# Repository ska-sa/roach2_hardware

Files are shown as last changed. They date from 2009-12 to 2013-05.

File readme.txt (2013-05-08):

Welcome to the GitHub repository for Roach 2 

change_log - contains details of the updates from rev 1 to Rev 2
design - contains calculations and estimates used in the design process
design_files - contains the Altium schematic and PCB files
release - contains the release files required for manufacturing and assembly

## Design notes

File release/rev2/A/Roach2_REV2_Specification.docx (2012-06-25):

PCB Specification

Date: | 1 June 2011
Company: | SKA SA
Billing Address: | 17 Baker St, Rosebank, Johannesburg, South Africa
| PO Box 522940, Saxonwold, 2132
Postal Address: | To be defined
Contact: | Omer Mahgoub | Email: | omer@ska.ac.za
| | Tel: | +27 21 506 7362
| Philip Gibbs | Email: | philip.gibbs@ska.ac.za
| | Tel: | +27 21 506 7363

Board name: ROACH 2

Revision: 2

Release: A

PCB Details

PCB Specifications: | IPC 6012 Class 2
Finished Board Size: | 12 x 9.6 inches [305x244 mm]
PCB Type: | Multi-layer
Layer Count: | 16
Dielectric: | All dielectric layers to be Isola 370HR high temperature laminate
Nominal board Thickness: | 93 mil (2.38 mm); tolerance +/-10%
Hole tolerance: | +3mil for vias; +/- 3mil for component holes and slots
Finish: | ENIG
Soldermask: | Green
Silkscreen: | White
Minimum clearance: | 4 mil
Handling rails: | .5 inch (12.7mm) rails, V-scored

PCB Stackup

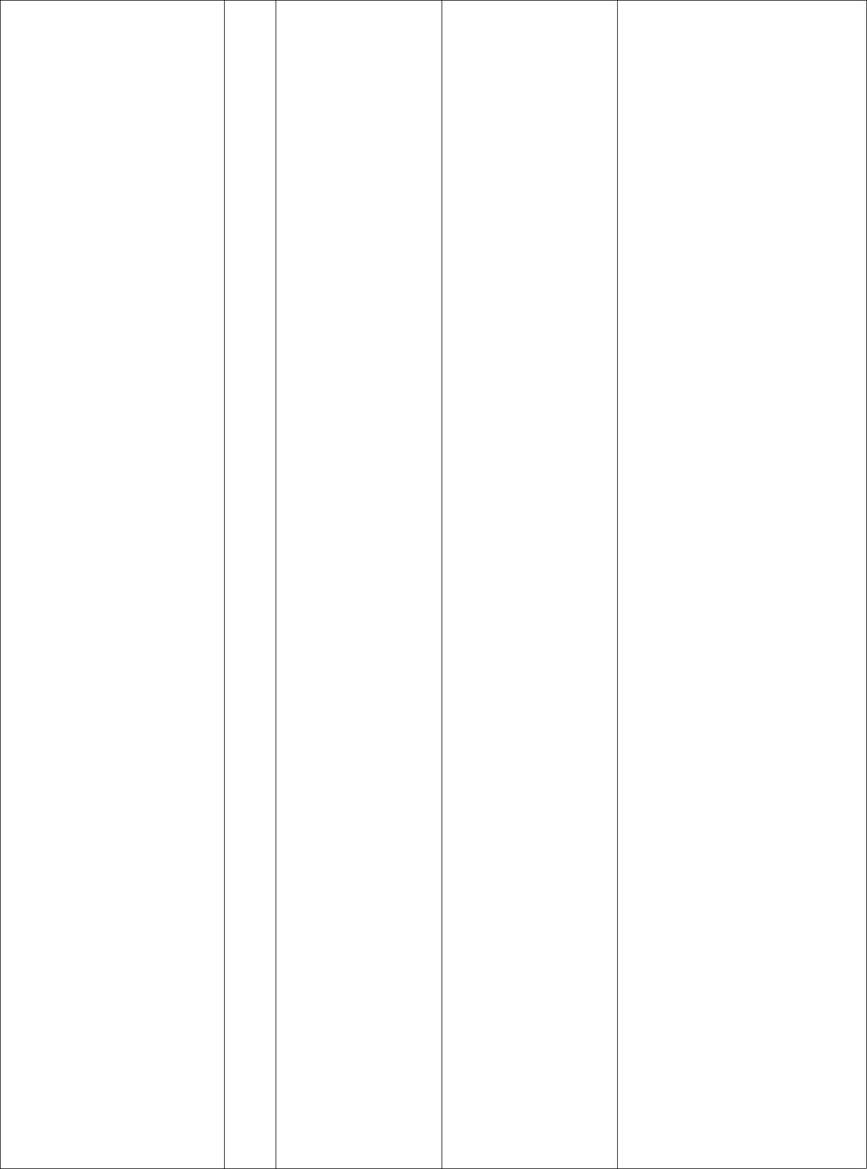
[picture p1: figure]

Layer | # | Copper (oz) | Dieletric (mil)** | Filename
Pastemask Top | | - | - | roach2.GTP
Silkscreen Top | | - | - | roach2.GTO
Soldermask Top | | - | - | roach2.GTS
Signal Top | 1 | 0.5 | | roach2.GTL
| | | 3mil
Ground 1 | 2 | 0.5 | | roach2.GP1
| | | 5mil
Signal 1 | 3 | 0.5 | | roach2.G1
| | | 5mil
Ground 2 | 4 | 0.5 | | roach2.GP2
| | | 5mil
Signal 2 | 5 | 0.5 | | roach2.G2
| | | 5mil
Power 1 | 6 | 1 | | roach2.GP3
| | | **
Ground 3 | 7 | 1 | | roach2.GP4
| | | 4mil
Signal 3 | 8 | 0.5 | | roach2.G3
| | | 4mil
Signal 4 | 9 | 0.5 | | roach2.G4
| | | 4mil
Power 2 | 10 | 1 | | roach2.GP5
| | | **
Power 3 | 11 | 1 | | roach2.GP6
| | | 5mil
Signal 5 | 12 | 0.5 | | roach2.G5
| | | 5mil
Power 4 | 13 | 0.5 | | roach2.GP7
| | | 5mil
Signal 6 | 14 | 0.5 | | roach2.G6
| | | 5mil
Ground 4 | 15 | 0.5 | | roach2.GP8
| | | 3mil
Signal Bottom | 16 | 0.5 | | roach2.GBL
Soldermask Bottom | | - | - | roach2.GBS
Silkscreen Bottom | | - | - | roach2.GBO
Pastemask Bottom | | - | - | roach2.GBP

* Thickness may be adjusted to achieve nominal total thickness of 93 mil, to satisfy impedance targets and to accommodate manufacturing processes.

Impedance Controlled Traces

All impedance matching to +/- 10%

Microstrip

Layers: Signal Top (#1), Signal Bottom (#16)

Target Impedance: 50 ohm

Trace thickness: 5 mil ( 127um )

Stripline

Layers: Layers: Signal 1 (#3), Signal 2 (#5), Signal 5 (#12), Signal 6 (#14)

Target Impedance: 50 ohm

Trace thickness: 3.8 mil ( 96.52 um )

Asymmetrical Stripline

Layers: Signal 3 (#8), Signal 4 (#9)

Target Impedance: 50 ohm

Trace thickness: 3.8 mil ( 96.52 um )

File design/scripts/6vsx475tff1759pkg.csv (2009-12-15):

N11 | 0 | INIT_B_0
N10 | 0 | DONE_0
AM11 | 0 | M1_0
AL10 | 0 | M2_0
P10 | 0 | HSWAPEN_0
M11 | 0 | PROGRAM_B_0
AL11 | 0 | M0_0
Y21 | 0 | AVSS_0
Y22 | 0 | AVDD_0
AA22 | 0 | VP_0
AB22 | 0 | VREFP_0
AB21 | 0 | VN_0
AA21 | 0 | VREFN_0
AC22 | 0 | DXP_0
AC21 | 0 | DXN_0
R10 | 0 | VBATT_0
L10 | 0 | DIN_0
J10 | 0 | RDWR_B_0
T10 | 0 | CSI_B_0
AK10 | 0 | DOUT_BUSY_0
K10 | 0 | CCLK_0
AR10 | 0 | TDO_0
AN10 | 0 | TCK_0
AN11 | 0 | TMS_0
AP10 | 0 | TDI_0
AH10 | 0 | VFS_0
AT37 | 12 | IO_L0P_12
AR38 | 12 | IO_L0N_12
AV39 | 12 | IO_L1P_12
AV38 | 12 | IO_L1N_12
AP37 | 12 | IO_L2P_12
AR37 | 12 | IO_L2N_12
AY39 | 12 | IO_L3P_12
BA39 | 12 | IO_L3N_12
AU37 | 12 | IO_L4P_12
AU38 | 12 | IO_L4N_VREF_12
AY38 | 12 | IO_L5P_12
AY37 | 12 | IO_L5N_12
AU36 | 12 | IO_L6P_12
AT36 | 12 | IO_L6N_12
BB39 | 12 | IO_L7P_12
BB38 | 12 | IO_L7N_12
AW37 | 12 | IO_L8P_SRCC_12
AW38 | 12 | IO_L8N_SRCC_12
AN35 | 12 | IO_L9P_MRCC_12
AN36 | 12 | IO_L9N_MRCC_12
AP36 | 12 | IO_L10P_MRCC_12
AP35 | 12 | IO_L10N_MRCC_12
BA37 | 12 | IO_L11P_SRCC_12
BB37 | 12 | IO_L11N_SRCC_12
AR35 | 12 | IO_L12P_VRN_12
AT35 | 12 | IO_L12N_VRP_12
BB36 | 12 | IO_L13P_12
BA36 | 12 | IO_L13N_12
AW36 | 12 | IO_L14P_12
AV36 | 12 | IO_L14N_VREF_12
BB34 | 12 | IO_L15P_12
BA34 | 12 | IO_L15N_12
AU34 | 12 | IO_L16P_12
AT34 | 12 | IO_L16N_12
BA35 | 12 | IO_L17P_12
AY35 | 12 | IO_L17N_12
AV34 | 12 | IO_L18P_12
AV35 | 12 | IO_L18N_12
AY34 | 12 | IO_L19P_12
AW35 | 12 | IO_L19N_12
AN40 | 13 | IO_L0P_13
AP40 | 13 | IO_L0N_13
AN41 | 13 | IO_L1P_13
AP41 | 13 | IO_L1N_13
AN39 | 13 | IO_L2P_13
AM39 | 13 | IO_L2N_13
AP42 | 13 | IO_L3P_13
AR42 | 13 | IO_L3N_13
AL37 | 13 | IO_L4P_13
AM38 | 13 | IO_L4N_VREF_13
AT42 | 13 | IO_L5P_13
AU42 | 13 | IO_L5N_13
AM34 | 13 | IO_L6P_13
AL35 | 13 | IO_L6N_13
AW42 | 13 | IO_L7P_13
AW41 | 13 | IO_L7N_13
AR40 | 13 | IO_L8P_SRCC_13
AT41 | 13 | IO_L8N_SRCC_13
AL34 | 13 | IO_L9P_MRCC_13
AK34 | 13 | IO_L9N_MRCC_13
AT40 | 13 | IO_L10P_MRCC_13
AU39 | 13 | IO_L10N_MRCC_13
AV41 | 13 | IO_L11P_SRCC_13
AU41 | 13 | IO_L11N_SRCC_13
AN38 | 13 | IO_L12P_VRN_13
AP38 | 13 | IO_L12N_VRP_13
AY42 | 13 | IO_L13P_13
BA42 | 13 | IO_L13N_13
AR39 | 13 | IO_L14P_13
AT39 | 13 | IO_L14N_VREF_13
BA41 | 13 | IO_L15P_13
BB41 | 13 | IO_L15N_13
AM37 | 13 | IO_L16P_13
AM36 | 13 | IO_L16N_13
BA40 | 13 | IO_L17P_13
AY40 | 13 | IO_L17N_13
AK35 | 13 | IO_L18P_13
AL36 | 13 | IO_L18N_13
AV40 | 13 | IO_L19P_13
AW40 | 13 | IO_L19N_13
AG34 | 14 | IO_L0P_14
AF34 | 14 | IO_L0N_14
AF40 | 14 | IO_L1P_14
AG41 | 14 | IO_L1N_14
AF39 | 14 | IO_L2P_14
AG39 | 14 | IO_L2N_14
AG42 | 14 | IO_L3P_14
AH41 | 14 | IO_L3N_14
AG38 | 14 | IO_L4P_14
AH38 | 14 | IO_L4N_VREF_14
AH40 | 14 | IO_L5P_14
AJ41 | 14 | IO_L5N_14
AF37 | 14 | IO_L6P_14
AG37 | 14 | IO_L6N_14
AJ42 | 14 | IO_L7P_14
AK42 | 14 | IO_L7N_14
AK38 | 14 | IO_L8P_SRCC_14
AJ38 | 14 | IO_L8N_SRCC_14
AH34 | 14 | IO_L9P_MRCC_14
AJ35 | 14 | IO_L9N_MRCC_14
AJ37 | 14 | IO_L10P_MRCC_14
AK37 | 14 | IO_L10N_MRCC_14
AH39 | 14 | IO_L11P_SRCC_14
AJ40 | 14 | IO_L11N_SRCC_14
AJ36 | 14 | IO_L12P_VRN_14
AH35 | 14 | IO_L12N_VRP_14
AL42 | 14 | IO_L13P_14
AM42 | 14 | IO_L13N_14
AG36 | 14 | IO_L14P_14
AH36 | 14 | IO_L14N_VREF_14
AL41 | 14 | IO_L15P_14
AM41 | 14 | IO_L15N_14
AF35 | 14 | IO_L16P_14
AF36 | 14 | IO_L16N_14
AK40 | 14 | IO_L17P_14
AL40 | 14 | IO_L17N_14
AF32 | 14 | IO_L18P_14
AG33 | 14 | IO_L18N_14
AK39 | 14 | IO_L19P_14
AL39 | 14 | IO_L19N_14
AE34 | 15 | IO_L0P_15
AE35 | 15 | IO_L0N_15
AB37 | 15 | IO_L1P_15
AB38 | 15 | IO_L1N_15
AE33 | 15 | IO_L2P_SM8P_15
AD33 | 15 | IO_L2N_SM8N_15
AB39 | 15 | IO_L3P_SM9P_15
AA40 | 15 | IO_L3N_SM9N_15
AC38 | 15 | IO_L4P_15
AC39 | 15 | IO_L4N_VREF_15
AA41 | 15 | IO_L5P_SM10P_15
AB41 | 15 | IO_L5N_SM10N_15
AE38 | 15 | IO_L6P_SM11P_15
AD38 | 15 | IO_L6N_SM11N_15
AA42 | 15 | IO_L7P_SM12P_15
AB42 | 15 | IO_L7N_SM12N_15
AC36 | 15 | IO_L8P_SRCC_15
AB36 | 15 | IO_L8N_SRCC_15
AD32 | 15 | IO_L9P_MRCC_15
AE32 | 15 | IO_L9N_MRCC_15
AE37 | 15 | IO_L10P_MRCC_15
AD37 | 15 | IO_L10N_MRCC_15
AC41 | 15 | IO_L11P_SRCC_15
AD41 | 15 | IO_L11N_SRCC_15
AB32 | 15 | IO_L12P_SM13P_15
AB33 | 15 | IO_L12N_SM13N_15
AC40 | 15 | IO_L13P_SM14P_15
AD40 | 15 | IO_L13N_SM14N_15
AD36 | 15 | IO_L14P_15
AD35 | 15 | IO_L14N_VREF_15
AD42 | 15 | IO_L15P_SM15P_15
AE42 | 15 | IO_L15N_SM15N_15
AC35 | 15 | IO_L16P_VRN_15
AB34 | 15 | IO_L16N_VRP_15
AF42 | 15 | IO_L17P_15
AF41 | 15 | IO_L17N_15
AC34 | 15 | IO_L18P_15
AC33 | 15 | IO_L18N_15
AE40 | 15 | IO_L19P_15
AE39 | 15 | IO_L19N_15
W37 | 16 | IO_L0P_16
Y37 | 16 | IO_L0N_16
U37 | 16 | IO_L1P_16
U38 | 16 | IO_L1N_16
W36 | 16 | IO_L2P_16
V36 | 16 | IO_L2N_16
U42 | 16 | IO_L3P_16
U41 | 16 | IO_L3N_16
AA36 | 16 | IO_L4P_16
AA37 | 16 | IO_L4N_VREF_16
U39 | 16 | IO_L5P_16
V39 | 16 | IO_L5N_16
W35 | 16 | IO_L6P_16
V35 | 16 | IO_L6N_16
V38 | 16 | IO_L7P_16
W38 | 16 | IO_L7N_16
AA35 | 16 | IO_L8P_SRCC_16
Y35 | 16 | IO_L8N_SRCC_16
W32 | 16 | IO_L9P_MRCC_16
Y33 | 16 | IO_L9N_MRCC_16
V34 | 16 | IO_L10P_MRCC_16
U34 | 16 | IO_L10N_MRCC_16
V40 | 16 | IO_L11P_SRCC_16
W40 | 16 | IO_L11N_SRCC_16
AA32 | 16 | IO_L12P_VRN_16
Y32 | 16 | IO_L12N_VRP_16
V41 | 16 | IO_L13P_16
W41 | 16 | IO_L13N_16
AA34 | 16 | IO_L14P_16
Y34 | 16 | IO_L14N_VREF_16
W42 | 16 | IO_L15P_16
Y42 | 16 | IO_L15N_16
U32 | 16 | IO_L16P_16
U33 | 16 | IO_L16N_16
Y40 | 16 | IO_L17P_16
Y39 | 16 | IO_L17N_16
V33 | 16 | IO_L18P_16
W33 | 16 | IO_L18N_16
Y38 | 16 | IO_L19P_16
AA39 | 16 | IO_L19N_16
M36 | 17 | IO_L0P_17
M37 | 17 | IO_L0N_17
L39 | 17 | IO_L1P_17
L40 | 17 | IO_L1N_17
M38 | 17 | IO_L2P_17
M39 | 17 | IO_L2N_17
L41 | 17 | IO_L3P_17
L42 | 17 | IO_L3N_17
N35 | 17 | IO_L4P_17
N34 | 17 | IO_L4N_VREF_17
N38 | 17 | IO_L5P_17
N39 | 17 | IO_L5N_17
N36 | 17 | IO_L6P_17
P37 | 17 | IO_L6N_17
M41 | 17 | IO_L7P_17
M42 | 17 | IO_L7N_17
R39 | 17 | IO_L8P_SRCC_17
P38 | 17 | IO_L8N_SRCC_17
P36 | 17 | IO_L9P_MRCC_17
P35 | 17 | IO_L9N_MRCC_17
T39 | 17 | IO_L10P_MRCC_17
R38 | 17 | IO_L10N_MRCC_17
N40 | 17 | IO_L11P_SRCC_17
N41 | 17 | IO_L11N_SRCC_17
R37 | 17 | IO_L12P_VRN_17
T37 | 17 | IO_L12N_VRP_17
P40 | 17 | IO_L13P_17
P41 | 17 | IO_L13N_17
R35 | 17 | IO_L14P_17
R34 | 17 | IO_L14N_VREF_17
P42 | 17 | IO_L15P_17
R42 | 17 | IO_L15N_17
U36 | 17 | IO_L16P_17
T36 | 17 | IO_L16N_17
R40 | 17 | IO_L17P_17
T40 | 17 | IO_L17N_17
T34 | 17 | IO_L18P_17
T35 | 17 | IO_L18N_17
T41 | 17 | IO_L19P_17
T42 | 17 | IO_L19N_17
AT26 | 21 | IO_L0P_21
AU27 | 21 | IO_L0N_21
AK22 | 21 | IO_L1P_21
AJ22 | 21 | IO_L1N_21
AY27 | 21 | IO_L2P_21
AW27 | 21 | IO_L2N_21
AM22 | 21 | IO_L3P_21
AL22 | 21 | IO_L3N_21
BA26 | 21 | IO_L4P_21
BA27 | 21 | IO_L4N_VREF_21
AJ23 | 21 | IO_L5P_21
AK23 | 21 | IO_L5N_21
BB26 | 21 | IO_L6P_21
BB27 | 21 | IO_L6N_21
AM23 | 21 | IO_L7P_21
AN23 | 21 | IO_L7N_21
AU23 | 21 | IO_L8P_SRCC_21
AU24 | 21 | IO_L8N_SRCC_21
AP25 | 21 | IO_L9P_MRCC_21
AP26 | 21 | IO_L9N_MRCC_21
AK24 | 21 | IO_L10P_MRCC_21
AL25 | 21 | IO_L10N_MRCC_21
AP23 | 21 | IO_L11P_SRCC_21
AR23 | 21 | IO_L11N_SRCC_21
AV24 | 21 | IO_L12P_VRN_21
AV25 | 21 | IO_L12N_VRP_21
AM24 | 21 | IO_L13P_21
AL24 | 21 | IO_L13N_21
BA25 | 21 | IO_L14P_21
AY25 | 21 | IO_L14N_VREF_21
AN24 | 21 | IO_L15P_21
AN25 | 21 | IO_L15N_21
AV26 | 21 | IO_L16P_21
AU26 | 21 | IO_L16N_21
AR24 | 21 | IO_L17P_21
AT24 | 21 | IO_L17N_21
AW25 | 21 | IO_L18P_21
AW26 | 21 | IO_L18N_21
AT25 | 21 | IO_L19P_21
AR25 | 21 | IO_L19N_21
AW30 | 22 | IO_L0P_22
AV30 | 22 | IO_L0N_22
AN26 | 22 | IO_L1P_22
AP27 | 22 | IO_L1N_22
AW31 | 22 | IO_L2P_22
AV31 | 22 | IO_L2N_22
AR28 | 22 | IO_L3P_22
AP28 | 22 | IO_L3N_22
AY32 | 22 | IO_L4P_22
AW32 | 22 | IO_L4N_VREF_22
AT29 | 22 | IO_L5P_22
AR29 | 22 | IO_L5N_22
BA32 | 22 | IO_L6P_22
AY33 | 22 | IO_L6N_22
AT30 | 22 | IO_L7P_22
AR30 | 22 | IO_L7N_22
BA30 | 22 | IO_L8P_SRCC_22
AY30 | 22 | IO_L8N_SRCC_22
AM26 | 22 | IO_L9P_MRCC_22
AL26 | 22 | IO_L9N_MRCC_22
AN28 | 22 | IO_L10P_MRCC_22
AM27 | 22 | IO_L10N_MRCC_22
AR27 | 22 | IO_L11P_SRCC_22
AT27 | 22 | IO_L11N_SRCC_22
AY29 | 22 | IO_L12P_VRN_22
BA29 | 22 | IO_L12N_VRP_22
AT31 | 22 | IO_L13P_22
AU31 | 22 | IO_L13N_22
BB33 | 22 | IO_L14P_22
BB32 | 22 | IO_L14N_VREF_22
AU29 | 22 | IO_L15P_22
AV29 | 22 | IO_L15N_22
BA31 | 22 | IO_L16P_22
BB31 | 22 | IO_L16N_22
AU28 | 22 | IO_L17P_22
AV28 | 22 | IO_L17N_22
BB29 | 22 | IO_L18P_22
BB28 | 22 | IO_L18N_22
AW28 | 22 | IO_L19P_22
AY28 | 22 | IO_L19N_22
AP30 | 23 | IO_L0P_23
AN30 | 23 | IO_L0N_23
AM31 | 23 | IO_L1P_23
AL31 | 23 | IO_L1N_23
AL29 | 23 | IO_L2P_23
AL30 | 23 | IO_L2N_23
AM33 | 23 | IO_L3P_23
AM32 | 23 | IO_L3N_23
AN29 | 23 | IO_L4P_23
AM29 | 23 | IO_L4N_VREF_23
AN33 | 23 | IO_L5P_23
AN34 | 23 | IO_L5N_23
AL27 | 23 | IO_L6P_23
AM28 | 23 | IO_L6N_23
AP31 | 23 | IO_L7P_23
AN31 | 23 | IO_L7N_23
AK28 | 23 | IO_L8P_SRCC_23
AK29 | 23 | IO_L8N_SRCC_23
AJ25 | 23 | IO_L9P_MRCC_23
AK25 | 23 | IO_L9N_MRCC_23
AH24 | 23 | IO_L10P_MRCC_23
AH25 | 23 | IO_L10N_MRCC_23
AR34 | 23 | IO_L11P_SRCC_23
AP33 | 23 | IO_L11N_SRCC_23
AH28 | 23 | IO_L12P_VRN_23
AJ28 | 23 | IO_L12N_VRP_23
AP32 | 23 | IO_L13P_23
AR32 | 23 | IO_L13N_23
AG28 | 23 | IO_L14P_23
AG27 | 23 | IO_L14N_VREF_23
AR33 | 23 | IO_L15P_23
AT32 | 23 | IO_L15N_23
AK27 | 23 | IO_L16P_23
AJ27 | 23 | IO_L16N_23
AU33 | 23 | IO_L17P_23
AU32 | 23 | IO_L17N_23
AJ26 | 23 | IO_L18P_23
AH26 | 23 | IO_L18N_23
AV33 | 23 | IO_L19P_23
AW33 | 23 | IO_L19N_23
AE30 | 24 | IO_L0P_GC_24
AF30 | 24 | IO_L0N_GC_24
W30 | 24 | IO_L1P_GC_24
V30 | 24 | IO_L1N_GC_24
AG32 | 24 | IO_L2P_D15_24
AF31 | 24 | IO_L2N_D14_24
T30 | 24 | IO_L3P_D13_24
R30 | 24 | IO_L3N_D12_24
AH31 | 24 | IO_L4P_D11_24
AG31 | 24 | IO_L4N_VREF_D10_24
N33 | 24 | IO_L5P_D9_24
P33 | 24 | IO_L5N_D8_24
AJ33 | 24 | IO_L6P_D7_24
AH33 | 24 | IO_L6N_D6_24
P32 | 24 | IO_L7P_D5_24
R33 | 24 | IO_L7N_D4_24
AK33 | 24 | IO_L8P_SRCC_24
AJ32 | 24 | IO_L8N_SRCC_24
Y30 | 24 | IO_L9P_MRCC_24
AA30 | 24 | IO_L9N_MRCC_24
AA31 | 24 | IO_L10P_MRCC_24
AB31 | 24 | IO_L10N_MRCC_24
R32 | 24 | IO_L11P_SRCC_24
T32 | 24 | IO_L11N_SRCC_24
AK32 | 24 | IO_L12P_D3_24
AL32 | 24 | IO_L12N_D2_FS2_24
T31 | 24 | IO_L13P_D1_FS1_24
U31 | 24 | IO_L13N_D0_FS0_24
AH30 | 24 | IO_L14P_FCS_B_24
AJ30 | 24 | IO_L14N_VREF_FOE_B_MOSI_24
V31 | 24 | IO_L15P_FWE_B_24
W31 | 24 | IO_L15N_RS1_24
AJ31 | 24 | IO_L16P_RS0_24
AK30 | 24 | IO_L16N_CSO_B_24
AC31 | 24 | IO_L17P_VRN_24
AC30 | 24 | IO_L17N_VRP_24
AH29 | 24 | IO_L18P_24
AG29 | 24 | IO_L18N_24
AD31 | 24 | IO_L19P_24
AD30 | 24 | IO_L19N_24
K33 | 25 | IO_L0P_25
K32 | 25 | IO_L0N_25
N28 | 25 | IO_L1P_25
P28 | 25 | IO_L1N_25
K35 | 25 | IO_L2P_25
K34 | 25 | IO_L2N_25
L31 | 25 | IO_L3P_25
L32 | 25 | IO_L3N_25
J37 | 25 | IO_L4P_25
J36 | 25 | IO_L4N_VREF_25
N29 | 25 | IO_L5P_25
N30 | 25 | IO_L5N_25
H39 | 25 | IO_L6P_25
H38 | 25 | IO_L6N_25
L35 | 25 | IO_L7P_25
L36 | 25 | IO_L7N_25
K38 | 25 | IO_L8P_SRCC_25
J38 | 25 | IO_L8N_SRCC_25
P27 | 25 | IO_L9P_MRCC_25
R27 | 25 | IO_L9N_MRCC_25
R28 | 25 | IO_L10P_MRCC_25
R29 | 25 | IO_L10N_MRCC_25
K37 | 25 | IO_L11P_SRCC_25
L37 | 25 | IO_L11N_SRCC_25
H40 | 25 | IO_L12P_25
H41 | 25 | IO_L12N_25
L34 | 25 | IO_L13P_25
M34 | 25 | IO_L13N_25
J40 | 25 | IO_L14P_25
J41 | 25 | IO_L14N_VREF_25
M33 | 25 | IO_L15P_25
M32 | 25 | IO_L15N_25
K39 | 25 | IO_L16P_VRN_25
K40 | 25 | IO_L16N_VRP_25
M31 | 25 | IO_L17P_25
N31 | 25 | IO_L17N_25
J42 | 25 | IO_L18P_GC_25
K42 | 25 | IO_L18N_GC_25
P30 | 25 | IO_L19P_GC_25
P31 | 25 | IO_L19N_GC_25
H36 | 26 | IO_L0P_26
G36 | 26 | IO_L0N_26
B37 | 26 | IO_L1P_26
A37 | 26 | IO_L1N_26
J35 | 26 | IO_L2P_26
H35 | 26 | IO_L2N_26
B38 | 26 | IO_L3P_26
A39 | 26 | IO_L3N_26
F37 | 26 | IO_L4P_26
E37 | 26 | IO_L4N_VREF_26
B39 | 26 | IO_L5P_26
C39 | 26 | IO_L5N_26
D38 | 26 | IO_L6P_26
C38 | 26 | IO_L6N_26
A40 | 26 | IO_L7P_26
A41 | 26 | IO_L7N_26
E39 | 26 | IO_L8P_SRCC_26
E38 | 26 | IO_L8N_SRCC_26
G34 | 26 | IO_L9P_MRCC_26
H34 | 26 | IO_L9N_MRCC_26
F35 | 26 | IO_L10P_MRCC_26
F36 | 26 | IO_L10N_MRCC_26
B41 | 26 | IO_L11P_SRCC_26
B42 | 26 | IO_L11N_SRCC_26
F39 | 26 | IO_L12P_VRN_26
G39 | 26 | IO_L12N_VRP_26
C40 | 26 | IO_L13P_26
C41 | 26 | IO_L13N_26
G37 | 26 | IO_L14P_26
G38 | 26 | IO_L14N_VREF_26
D42 | 26 | IO_L15P_26
D41 | 26 | IO_L15N_26
F40 | 26 | IO_L16P_26
F41 | 26 | IO_L16N_26
D40 | 26 | IO_L17P_26
E40 | 26 | IO_L17N_26
G41 | 26 | IO_L18P_26
G42 | 26 | IO_L18N_26
E42 | 26 | IO_L19P_26
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

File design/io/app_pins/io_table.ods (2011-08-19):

Usage | IO count | IO
DDR3 | 132 | 1v5 | 3.3 | No unbuffered support(-1 clk pair), no SPD, no parity
QDR0..3 | 408 | 1v5 | 10.2 | No echo clock, no qvld
ZDOK0..1 | 160 | 2v5 | 4
EPB | 70 | 2v5 | 1.75 | 32 bit data, 26 address lines (only 1 peripheral dma channel)
Clocks | 8 | 2v5 | 0.2 | Notes: 1 EXT CLK, 1 Sync IN, 1 Sync Out, 1 100 MHz sysclk
SFP+ | 10 | 1v5 |  | TBD: what scheme should be used (discuss with netfpga crowd)
GPIO | 18 | 1v5 | 0.45 | sixteen GPIO, 2 oe_n, NO dedicated LEDs
user used | 806
infr used | 34
total used | 840
Available | 840
Free | 0 | 1v5

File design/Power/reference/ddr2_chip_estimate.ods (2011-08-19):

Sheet: Title
File Name | : | DDR2_Power_Calc_16.XLS
Revision | : | 1.6
Date | : | December 15, 2006
E-Mail | : | dramsupport@micron.com
Company | : | Micron Technology, Inc.
Description | : | Calculates the power consumed by a DDR2 SDRAM based on system use parameters and the device data sheet.
Limitations | :
Notes | :
Disclaimer | : | THIS SPREADSHEET IS FOR ESTIMATING PURPOSES ONLY. ANY INFORMATION PROVIDED HEREIN IS PROVIDED "AS IS" AND WITHOUT WARRANTIES OF ANY KIND. MICRON WARRANTS ONLY THAT ITS PRODUCTS COMPLY WITH MICRON'S SPECIFICATION SHEET FOR THE PRODUCT AT THE TIME OF DELIVERY; PROVIDED THAT DEVIATIONS FROM SPECIFICATIONS WHICH DO NOT MATERIALLY AFFECT FORM, FIT OR FUNCTION OF SUCH PRODUCT IN THE SYSTEM AND CONFIGURATION IN OR FOR WHICH IT IS INITIALLY INSTALLED OR QUALIFIED BY CUSTOMER SHALL NOT BE DEEMED TO CONSTITUTE FAILURE TO COMPLY WITH SUCH SPECIFICATIONS.
 |  | SEE MICRON'S STANDARD TERMS AND CONDITIONS OF SALE FOR COMPLETE WARRANTY DETAILS.
 |  | Copyright © 2007 Micron Semiconductor Products, Inc.
 |  | All rights reserved.

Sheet: Instructions
Instructions for Use
 | DDR2 Spec tab (ALL MUST BE VERIFIED FOR A SPECIFIC DRAM DATA SHEET)
 |  | Inputs are required for all densities and speed grades that may be chosen.
 |  | Enter VDD tolerance range in rows 6-7.
 |  | Enter IDD values for the speed grade under investigation in rows 9-26. Note that there are entries for both x4/x8 devices, as well as x16. Also note the two separate entries for IDD3P, depending on the mode register setting.
 |  | Timing restrictions in rows 28-36 are entered from the data sheet. These determine the test conditions for the IDD values and restrictions of normal device operation.
 | DDR2 Config Spec tab (ALL MUST BE ENTERED TO IDENTIFY DRAM TO BE USED FOR POWER CALCULATION)
 |  | Row 7 selects which DRAM density
 |  | Row 8 selects number of DQs
 |  | Row 9 selects the starting speed grade
 |  | Row 10 selects if differential strobe is enabled or not
 |  | Row 11 selects if RDQ is enabled or not (only applicable on x8 devices)
 |  | Row 12 selects if fast or slow exit is used for power-down exit
 | Usage Conditions tab (ALL MUST BE ENTERED FOR SPECIFIC SYSTEM)
 |  | Row 7 is the actual VDD the system is operating at. It is usually set to nominal conditions.
 |  | Row 8 is the clock rate the DRAM is operating at. This is one half of the data rate.
 |  | Row 9 is the burst length programmed in the mode register. (The model does not calculate power if burst interrupt is utilized.)
 |  | Row 10 is the amount of power that is drawn per output while driving data. This is system-dependent and must be calculated. The value may be approximated with a DC calculation or more accurately determined using SPICE models.
 |  | Row 11 is the amount of power that is drawn per output while terminating write data to itself. This is system-dependent and must be calculated. The value may be approximated with a DC calculation or more accurately determined using SPICE models.
 |  | Row 12 is the amount of power that is drawn per DQ while terminating read data going to a different DRAM. This is system- dependent and must be calculated. The value may be approximated with a DC calculation or more accurately determined using SPICE models.
 |  | Row 13 is the amount of power that is drawn per DQ while terminating write data going to a different DRAM. This is system- dependent and must be calculated. The value may be approximated with a DC calculation or more accurately determined using SPICE models.
 |  | Row 15 is the time when all banks are in a precharged state. This is the amount of time when no bank has been activated.
 |  | Row 16 is the percentage of time that all that banks are precharged when the device is in power-down state. This is the percentage of time when the DRAM is using IDD2P versus IDD2F.
 |  | Row 17 is the percentage of DRAM active time when CKE is LOW and the device is in the power-down state. This is the percentage of active time when the DRAM is using IDD3P current versus IDD3N.
 |  | Row 19 is the average time between ACT commands to the DRAM. Under IDD0 or IDD1 conditions, this would be equal to tRC. If the DRAM is in interleaving bursts, it may be less than tRC. This value is now calculated off of page hit rate. Entering a number here will override the automatic calculation.
 |  | Row 21 is the percentage of clocks that data is read from the DRAM. This would be equal to the average read bandwidth divided by peak read bandwidth.
 |  | Row 22 is the percentage of clocks that data is written to the DRAM. This would be equal to the average read bandwidth divided by peak read bandwidth.
 |  | Row 23 is the page hit rate. 0% means there are no page hits (i.e., one read/write per each activate).
 |  | Row 24 is the percentage of clock cycles the DRAM under investigation is terminating read data from another device. It does not include time when a different DRAM on the bus may be terminating data.
 |  | Row 25 is the percentage of clock cycles the DRAM under investigation is terminating write data from another device. It does not include time when a different DRAM on the bus may be terminating data.
 | Power Calcs tab
 |  | No inputs are required for this tab. It contains some of the detail calculations that provide information into the Summary tab. It can be used as a reference for further understanding the calculator, or you may jump straight to the Summary page for the final answer.
 | Summary tab
 |  | No inputs are required for this tab. It contains a summary of the power used by the DRAM. The power is broken out between: -power to read/write data to and from the DRAM - power to activate the rows - background power for standby modes and refresh

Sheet: DDR2 Spec
 |  |  | 256Mb - All Revs |  |  |  |  |  | 512Mb - All Revs |  |  |  |  |  | 1Gb - Die Rev A values |  |  |  |  |  | 1Gb - Die Rev E values |  |  |  |  |  | 2Gb - All revs
Parameter | Condition | Condition | -25E | -25 | -3E | -3 | -37E | -5E | -25E | -25 | -3E | -3 | -37E | -5E | -25E | -25 | -3E | -3 | -37E | -5E | -25E | -25 | -3E | -3 | -37E | -5E | -25E | -25 | -3E | -3 | -37E | -5E
 | Maximum VDD |  | 1.9 | 1.9 | 1.9 | 1.9 | 1.9 | 1.9 | 1.9 | 1.9 | 1.9 | 1.9 | 1.9 | 1.9 | 1.9 | 1.9 | 1.9 | 1.9 | 1.9 | 1.9 | 1.9 | 1.9 | 1.9 | 1.9 | 1.9 | 1.9 | 1.9 | 1.9 | 1.9 | 1.9 | 1.9 | 1.9 | V
 | Minimum VDD |  | 1.7 | 1.7 | 1.7 | 1.7 | 1.7 | 1.7 | 1.7 | 1.7 | 1.7 | 1.7 | 1.7 | 1.7 | 1.7 | 1.7 | 1.7 | 1.7 | 1.7 | 1.7 | 1.7 | 1.7 | 1.7 | 1.7 | 1.7 | 1.7 | 1.7 | 1.7 | 1.7 | 1.7 | 1.7 | 1.7 | V
IDD0 | Maximum active precharge current | x4/x8 | 100 | 100 | 90 | 90 | 80 | 75 | 100 | 100 | 90 | 90 | 80 | 80 | 100 | 100 | 90 | 90 | 80 | 70 | 90 | 90 | 85 | 85 | 70 | 70 | TBD | TBD | 100 | 100 | 90 | 90 | mA
 |  | x16 | 100 | 100 | 90 | 90 | 80 | 75 | 135 | 135 | 120 | 120 | 110 | 110 | 150 | 150 | 135 | 135 | 110 | 110 | 150 | 150 | 135 | 135 | 110 | 110 | TBD | TBD | 135 | 135 | 115 | 115 | mA
IDD2P | Maximum precharge power-down standby current | x4/x8 | 5 | 5 | 5 | 5 | 5 | 5 | 7 | 7 | 5 | 5 | 5 | 5 | 7 | 7 | 7 | 7 | 7 | 7 | 7 | 7 | 7 | 7 | 7 | 7 | TBD | TBD | 8 | 8 | 8 | 8 | mA
 |  | x16 | 5 | 5 | 5 | 5 | 5 | 5 | 7 | 7 | 5 | 5 | 5 | 5 | 7 | 7 | 7 | 7 | 7 | 7 | 7 | 7 | 7 | 7 | 7 | 7 | TBD | TBD | 8 | 8 | 8 | 8 | mA
IDD2N | Maximum precharge standby current | x4/x8 | 45 | 45 | 40 | 40 | 35 | 30 | 55 | 55 | 55 | 55 | 45 | 40 | 70 | 70 | 70 | 70 | 45 | 40 | 50 | 50 | 40 | 40 | 40 | 35 | TBD | TBD | 60 | 60 | 50 | 45 | mA
 |  | x16 | 45 | 45 | 40 | 40 | 35 | 30 | 70 | 70 | 60 | 60 | 50 | 45 | 80 | 80 | 80 | 80 | 50 | 40 | 80 | 80 | 70 | 70 | 50 | 40 | TBD | TBD | 70 | 70 | 60 | 50 | mA
IDD3P Fast | Maximum active power-down standby current (fast Exit) | x4/x8 | 35 | 35 | 30 | 30 | 25 | 20 | 40 | 40 | 35 | 35 | 30 | 25 | 45 | 45 | 45 | 45 | 35 | 35 | 40 | 40 | 30 | 30 | 30 | 30 | TBD | TBD | 40 | 40 | 35 | 30 | mA
 |  | x16 | 35 | 35 | 30 | 30 | 25 | 20 | 40 | 40 | 35 | 35 | 30 | 25 | 45 | 45 | 45 | 45 | 35 | 35 | 40 | 40 | 30 | 30 | 30 | 30 | TBD | TBD | 40 | 40 | 35 | 30 | mA
IDD3P Slow | Maximum active power-down standby current (slow Exit) | x4/x8 | 6 | 6 | 6 | 6 | 6 | 6 | 12 | 12 | 10 | 10 | 10 | 10 | 14 | 14 | 14 | 14 | 14 | 14 | 10 | 10 | 10 | 10 | 10 | 10 | TBD | TBD | 10 | 10 | 10 | 10 | mA
 |  | x16 | 6 | 6 | 6 | 6 | 6 | 6 | 12 | 12 | 10 | 10 | 10 | 10 | 14 | 14 | 14 | 14 | 14 | 14 | 10 | 10 | 10 | 10 | 10 | 10 | TBD | TBD | 10 | 10 | 10 | 10 | mA
IDD3N | Maximum active standby current | x4/x8 | 55 | 55 | 50 | 50 | 40 | 30 | 70 | 70 | 65 | 65 | 55 | 45 | 75 | 75 | 75 | 75 | 55 | 45 | 60 | 60 | 55 | 55 | 45 | 40 | TBD | TBD | 55 | 55 | 45 | 40 | mA
 |  | x16 | 65 | 65 | 55 | 55 | 40 | 30 | 75 | 75 | 70 | 70 | 60 | 50 | 85 | 85 | 85 | 85 | 60 | 55 | 85 | 85 | 75 | 75 | 60 | 55 | TBD | TBD | 75 | 75 | 55 | 50 | mA
IDD4R | Maximum read burst current | x4/x8 | 210 | 210 | 180 | 180 | 150 | 115 | 205 | 205 | 175 | 175 | 145 | 115 | 190 | 190 | 190 | 190 | 145 | 110 | 160 | 160 | 135 | 135 | 125 | 105 | TBD | TBD | 170 | 170 | 150 | 140 | mA
 |  | x16 | 220 | 220 | 190 | 190 | 160 | 120 | 275 | 275 | 235 | 235 | 195 | 155 | 320 | 320 | 320 | 320 | 180 | 160 | 320 | 320 | 220 | 220 | 180 | 160 | TBD | TBD | 275 | 275 | 195 | 180 | mA
IDD4W | Maximum write burst current | x4/x8 | 220 | 220 | 190 | 190 | 160 | 125 | 195 | 195 | 155 | 155 | 130 | 110 | 185 | 185 | 185 | 185 | 130 | 110 | 160 | 160 | 135 | 135 | 125 | 105 | TBD | TBD | 150 | 150 | 130 | 125 | mA
 |  | x16 | 250 | 250 | 215 | 215 | 180 | 140 | 295 | 295 | 230 | 230 | 190 | 150 | 315 | 315 | 315 | 315 | 180 | 160 | 315 | 315 | 200 | 200 | 180 | 160 | TBD | TBD | 250 | 250 | 190 | 160 | mA
IDD5A | Maximum burst refresh current | x4/x8 | 200 | 200 | 180 | 180 | 170 | 165 | 230 | 230 | 210 | 210 | 200 | 190 | 280 | 280 | 270 | 270 | 250 | 220 | 235 | 235 | 215 | 215 | 210 | 205 | TBD | TBD | 280 | 280 | 260 | 250 | mA
 |  | x16 | 200 | 200 | 180 | 180 | 170 | 165 | 230 | 230 | 220 | 220 | 210 | 200 | 280 | 280 | 270 | 270 | 250 | 240 | 280 | 280 | 270 | 270 | 250 | 240 | TBD | TBD | 280 | 280 | 260 | 250 | mA
 | tCK used for current measurements (see current notes) |  | 2.5 | 2.5 | 3 | 3 | 3.75 | 5 | 2.5 | 2.5 | 3 | 3 | 3.75 | 5 | 2.5 | 2.5 | 3 | 3 | 3.75 | 5 | 2.5 | 2.5 | 3 | 3 | 3.75 | 5 | TBD | TBD | 3 | 3 | 3.75 | 5 | ns
tRRD | Minimum activate-to-activate timing (different bank) | x4/x8 | 7.5 | 7.5 | 7.5 | 7.5 | 7.5 | 7.5 | 7.5 | 7.5 | 7.5 | 7.5 | 7.5 | 7.5 | 7.5 | 7.5 | 7.5 | 7.5 | 7.5 | 7.5 | 7.5 | 7.5 | 7.5 | 7.5 | 7.5 | 7.5 | TBD | TBD | 7.5 | 7.5 | 7.5 | 7.5 | ns
 |  | x16 | 10 | 10 | 10 | 10 | 10 | 10 | 10 | 10 | 10 | 10 | 10 | 10 | 10 | 10 | 10 | 10 | 10 | 10 | 10 | 10 | 10 | 10 | 10 | 10 | TBD | TBD | 10 | 10 | 10 | 10 | ns
tRC | Minimum activate-to-activate timing (same bank) |  | 57.5 | 60 | 57 | 60 | 60 | 55 | 57.5 | 60 | 57 | 60 | 60 | 55 | 57.5 | 60 | 57 | 60 | 60 | 55 | 57.5 | 60 | 57 | 60 | 60 | 55 | TBD | TBD | 54 | 55 | 55 | 55 | ns
tRAS | tRAS used for IDD0 calculation |  | 45 | 45 | 45 | 45 | 45 | 40 | 45 | 45 | 45 | 45 | 45 | 40 | 45 | 45 | 45 | 45 | 45 | 40 | 45 | 45 | 45 | 45 | 45 | 40 | TBD | TBD | 40 | 40 | 40 | 40 | ns
tRFC (MIN) | Minimum refresh-to-refresh cycle time |  | 75 | 75 | 75 | 75 | 75 | 75 | 105 | 105 | 105 | 105 | 105 | 105 | 127.5 | 127.5 | 127.5 | 127.5 | 127.5 | 127.5 | 127.5 | 127.5 | 127.5 | 127.5 | 127.5 | 127.5 | TBD | TBD | 197.5 | 197.5 | 197.5 | 197.5 | ns
tREFI | Average periodic refresh cycle time |  | 7.8 | 7.8 | 7.8 | 7.8 | 7.8 | 7.8 | 7.8 | 7.8 | 7.8 | 7.8 | 7.8 | 7.8 | 7.8 | 7.8 | 7.8 | 7.8 | 7.8 | 7.8 | 7.8 | 7.8 | 7.8 | 7.8 | 7.8 | 7.8 | TBD | TBD | 7.8 | 7.8 | 7.8 | 7.8 | µs
tCK (MIN) | Minimum tCK cycle rate |  | 2.5 | 2.5 | 3 | 3 | 3.75 | 5 | 2.5 | 2.5 | 3 | 3 | 3.75 | 5 | 2.5 | 2.5 | 3 | 3 | 3.75 | 5 | 2.5 | 2.5 | 3 | 3 | 3.75 | 5 | TBD | TBD | 3 | 3 | 3.75 | 5 | ns
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

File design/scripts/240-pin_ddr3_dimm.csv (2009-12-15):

1 | 1 | VREFDQ
2 | 1 | VSS
3 | 0 | DQ0
4 | 0 | DQ1
5 | 1 | VSS
6 | 0 | DQS0_c
7 | 0 | DQS0_t
8 | 1 | VSS
9 | 0 | DQ2
10 | 0 | DQ3
11 | 1 | VSS
12 | 0 | DQ8
13 | 0 | DQ9
14 | 1 | VSS
15 | 0 | DQS1_c
16 | 0 | DQS1_t
17 | 1 | VSS
18 | 0 | DQ10
19 | 0 | DQ11
20 | 1 | VSS
21 | 0 | DQ16
22 | 0 | DQ17
23 | 1 | VSS
24 | 0 | DQS2_c
25 | 0 | DQS2_t
26 | 1 | VSS
27 | 0 | DQ18
28 | 0 | DQ19
29 | 1 | VSS
30 | 0 | DQ24
31 | 0 | DQ25
32 | 1 | VSS
33 | 0 | DQS3_c
34 | 0 | DQS3_t
35 | 1 | VSS
36 | 0 | DQ26
37 | 0 | DQ27
38 | 1 | VSS
39 | 0 | CB0
40 | 0 | CB1
41 | 1 | VSS
42 | 0 | DQS8_c
43 | 0 | DQS8_t
44 | 1 | VSS
45 | 0 | CB2
46 | 0 | CB3
47 | 1 | VSS
48 | 1 | VTT
49 | 1 | VTT
50 | 0 | CKE0
51 | 1 | VDD
52 | 0 | BA2
53 | 0 | Err_Out_n
54 | 1 | VDD
55 | 0 | A11
56 | 0 | A7
57 | 1 | VDD
58 | 0 | A5
59 | 0 | A4
60 | 1 | VDD
61 | 0 | A2
62 | 1 | VDD
63 | 0 | CK1_t
64 | 0 | CK1_c
65 | 1 | VDD
66 | 1 | VDD
67 | 1 | VREFCA
68 | 0 | Par_In
69 | 1 | VDD
70 | 0 | A10/AP
71 | 0 | BA0
72 | 1 | VDD
73 | 0 | WE_n
74 | 0 | CAS_n
75 | 1 | VDD
76 | 0 | S1_n
77 | 0 | ODT1
78 | 1 | VDD
79 | 0 | S2_n
80 | 1 | VSS
81 | 0 | DQ32
82 | 0 | DQ33
83 | 1 | VSS
84 | 0 | DQS4_c
85 | 0 | DQS4_t
86 | 1 | VSS
87 | 0 | DQ34
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

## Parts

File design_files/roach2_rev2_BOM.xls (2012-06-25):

POD number | Manufacturer | PartNum | Description | Designator | Rating | Tolerance | Value | Quantity
RESN-CLK-7 | Crystek | C3392-48.00 | 48 MHz, 3V3, Surface mount, Clock Oscillator | U35 |  |  |  | 1
CONN-PCB-13 | 3M | 8510-4500PL | 2x5, 2.54 mm Pitch, Through-hole, 1 Amp, Female Header | P1 |  |  |  | 1
CONN-PCB-10 | 3M | N2520-6V0C-RB-WE | 2x10, 2.54mm Pitch, Male Shrouded Header | P13, P15 |  |  |  | 2
CONN-PCB-17 | Amphenol | 132134 | PCB-Mounted, Vertical, SMA Connector | J9, J10, J11 |  |  |  | 3
IC-MON-6 | Analog Devices | AD7414ARTZ-1 | 0.5 C Accurate, 10-bit Temperature Sensor | U15, U18 |  |  |  | 2
IC-LOG-7 | Analog Devices | ADCMP605BCPZ | Rail-to-Rail, Very Fast, 2.5 V to 5.5 V, Single-Supply LVDS Comparators | U67, U69 |  |  |  | 2
IC-CPU-1 | Applied Micro | PPC440EPX-NUA667T | 667MHz, non-RoHS, PPC440EPx uProcessor | U2 |  |  |  | 1
IC-MEM-4 | Atmel | AT24HC04B-TH-B | 4K Serial EEPROM | U38 |  |  |  | 1
CAP-TAN-6 | AVX | TPSB107M006R0200 | 100uF, Low ESR, Tantalum Capacitor | C5, C6, C23, C68, C69, C94, C95, C130, C131, C132, C133, C673, C674, C675, C676, C677, C678 | 6.3V | 20% | 100uF | 17
ELMECH-SW-1 | BOURNS | 7914J-1-000-E | 4mm, Surface mount, Sealed Key Switch | S1, S4, S5 |  |  |  | 3
RESN-CLK-2 | Crystek | CCLD-023-25-100.000 | 100.00 MHz, Low-Jitter Differential LVDS Clock Oscillator | U72 |  |  |  | 1
RESN-CLK-3 | Crystek | CCLD-023-25-125.000 | 125.00 MHz, Low-Jitter Differential LVDS Clock Oscillator | U55 |  |  |  | 1
RESN-CLK-4 | Crystek | CCLD-023-25-156.250 | 156.25 MHz, Low-Jitter Differential LVDS Clock Oscillator | U56 |  |  |  | 1
RESN-XTAL-4 | CTS | 405C35D12M00000 | 12 MHz, Surface mount, Crystal Oscillator | Y4 |  |  |  | 1
RESN-CLK-5 | CTS | 636N5C025M00000 | 25.00 MHz, 2V5, CTS 636 clock oscillator | Y6, Y7 |  |  |  | 2
RESN-CLK-1 | CTS | CB3LV-3C-33M3333 | Surface mount, 33.3333 MHz, 3V3 Clock, oscillator | Y2, Y5 |  |  |  | 2
IC-MEM-1 | Cypress | CY7C2565KV18-450BZXC | 72Mb, 36-Bit wide, QDR2+ Synchronous SRAM with ODT | U57, U58, U60, U61 |  |  |  | 4
TRANS-NFET-0 | Fairchild Semiconductor | BSS138 | N-Channel Logic Level Enhancement Mode Field Effect Transistor | Q3, Q4, Q5, Q10, Q11, Q12, Q13, Q14, Q15, Q16, Q17, Q18, Q19, Q20, Q21, Q22, Q23, Q24, Q25, Q26, Q27, Q28 | 0.22A |  |  | 22
IC-LOG-0 | Fairchild Semiconductor | NC7S08M5X | TinyLogic® HS 2-Input AND Gate | U86 |  |  |  | 1
TRANS-NFET-1 | Fairchild Semiconductor | NDS331N | N-Channel Logic Level Enhancement Mode Field Effect Transistor | Q1, Q2, Q6, Q7, Q8, Q9 | 1.3A |  |  | 6
IC-IF-0 | FTDI | FT4232HQ | Quad High Speed USB to Multipurpose UART/MPSSE | U33 |  |  |  | 1
CONN-PCB-4 | HALO | HFJ11-1G02E-L55 | RJ45 with Integrated magnetic and dual LEDs | P9, P12 |  |  |  | 2
ELMECH-BAT-4 | Harwin | S8401-46 | Vertical, Through Hole Mount CR 2032, 20mm Coin Cell Retainer | BT1 |  |  |  | 1
IC-LOG-9 | Intersil | ICL3225EIAZ | Low-power RS232 transceivers | U36 |  |  |  | 1
CAP-TAN-0 | KEMET | T491X227M010AT | 220uF, Solid Tantalum Chip Capacitor | C182 | 10V | 20% | 220uF | 1
CAP-TAN-2 | KEMET | T520D337M006ATE045 | 330uF, Conductive Polymer Chip Capacitor | C303, C304, C305, C306, C307, C308, C309, C310, C311, C326, C344, C632 | 6.3V | 20% | 330uF | 12
CAP-TAN-1 | KEMET | T520T476M006ATE070 | 47uF, Conductive Polymer Chip Capacitor | C312, C313, C314, C315, C316, C317, C361, C362, C363, C373, C374, C375, C376, C385, C387, C388, C389, C394, C395, C396, C403, C408, C415, C418, C710, C711, C712, C713, C714, C715, C716, C717 | 6.3V | 20% | 47uF | 32
CAP-TAN-8 | KEMET | T520Y687M004ATE015 | 680uF, Conductive Polymer Chip Capacitor | C3, C19 | 4V | 20% | 680uF | 2
CAP-TAN-4 | KEMET | T530X158M2R5ATE005 | 1500uF, Conductive Polymer Chip Capacitor | C28, C34 | 2V5 | 20% | 1500uF | 2
IC-MON-8 | Linear Technology | LTC2954CTS8-1#TRMPBF | Push Button On/Off Controller | U12 |  |  |  | 1
ELMECH-FUSE-0 | Littelfuse | 1206L050-C | Resettable, Surface mount Fuse | F1, F2, F3, F4, F5, F6, F7, F8, F9 | 500mA |  |  | 9
ELMECH-ESD-3 | Littelfuse | PGB1010402 | Surface Mount Polymeric ESD Suppressor in an 0402 package | SP4, SP5, SP6, SP7, SP8, SP9, SP10, SP11, SP12, SP13, SP14, SP15, SP16, SP17, SP18, SP19, SP20, SP21, SP22, SP23, SP24, SP25, SP26, SP27, SP28, SP29, SP30, SP31, SP32, SP33, SP34, SP35, SP36, SP38, SP39, SP40, SP41, SP42, SP43, SP44, SP45, SP46 |  |  |  | 42
ELMECH-ESD-4 | Littelfuse | PGB102ST23WR | Ultra-low Capacitance, Surface mount ESD Suppressor | SP1, SP2 |  |  |  | 2
ELMECH-ESD-2 | Littelfuse | V5.5MLA0603 | Multilayer Transient Voltage Surge Suppressing Varistor | VR1, VR2 |  |  |  | 2
OPTO-LED-0 | LUMEX | SML-LX1206GC-TR | Green, Surface mount, LED, 1206 | DS3, DS4, DS5, DS6, DS9, DS10, DS11, DS12, DS15, DS16, DS17, DS18, DS19, DS20, DS21, DS22, DS23, DS24, DS25, DS29 | 20mA |  |  | 20
OPTO-LED-1 | LUMEX | SML-LX1206IC-TR | Red, Surface mount, LED, 1206 | DS1, DS7, DS26, DS27, DS28 | 20mA |  |  | 5
IC-PHY-1 | Marvell | 88E1111-XX-BAB1C000 | Integrated 10/100/1000 Ultra Gigabit Ethernet Transceiver | U50, U64 |  |  |  | 2
IC-MON-5 | Maxim | DS1307Z+ | I2C Real-Time Clock | U11 |  |  |  | 1
IC-MON-7 | MAXIM | DS32KHZS# | Temperature Compensated, 32.768 kHz Crystal Oscillator | U85 |  |  |  | 1
IC-MON-3 | Maxim | MAX16071ETL+ | 8-Channel, Flash-Configurable System Monitor with Nonvolatile Fault Registers | U16, U23 |  |  |  | 2
IC-MON-1 | Maxim | MAX1805MEE | Multichannel Remote/Local Temperature Sensors | U22 |  |  |  | 1
IC-MON-2 | MAXIM | MAX6650EUB | Fan-Speed Regulators and Monitors with SMBus/I2C-Compatible Interface | U13, U17, U21, U26 |  |  |  | 4
IC-MON-4 | Micrel | MIC2774N-29YM5 | Dual-power low voltage supervisor | U10, U29, U92 |  |  |  | 3
IC-LOG-14 | Micrel | SY89832UMG | 2.5 C Ultra-precision 1:4 LVDS Fanout Buffer/Translator with Interal Termination | U32, U54, U84 |  |  |  | 3
IC-MEM-3 | Microchip | 93LC56B/SN | 2K Microwire Compatible Serial EEPROM | U34 |  |  |  | 1
IC-MEM-2 | Micron | MT47H128M16HG-37E | 2Gb, x16, BGA84 DDR2 SDRAM IC | U42, U43, U44, U45 |  |  |  | 4
CONN-PCB-12 | Molex | 0015912100 | 2x5, 2.54 mm Pitch, Male Header | P6, P14 |  |  |  | 2
CONN-PCB-14 | Molex | 0022032021 | 1x2, 2.56mm, Header/Jumper | JP1, JP2 |  |  |  | 2
CONN-PCB-6 | Molex | 0022232031 | 3-pin ATX Fan Connector | J2, J3, J4, J5 |  |  |  | 4
CONN-PCB-5 | Molex | 0442060007 | 24-Pin ATX Connector | J1 |  |  |  | 1
CONN-PCB-18 | Molex | 0894858001 | Right angle, Through-hole, USB Type A Receptacle | P4 |  |  |  | 1
CONN-PCB-24 | Molex | 5.035e+009 | Push/Push SD Card Connector with Card Detection | P8 |  |  |  | 1
CONN-PCB-25 | Molex | 67068-8001 | Right angle, Through-hole, USB Type B Receptacle | P3 |  |  |  | 1
IND-FB-2 | Murata | BLM18PG181SN1 | 180 Ohm, Chip Ferrite Brad | L8, L11, L14 | 1500mA | 25% | 180R | 3
IND-FB-0 | Murata | BLM21BD601SN1 | 600 Ohm, Chip Ferrite Bead | L9, L10, L12, L13, L15, L16, L17, L18, L19, L20, L21, L23, L24, L25, L26 | 200mA | 25% | 600R | 15
IND-FB-1 | Murata | BLM31PG121SN1 | 120 Ohm, Chip Ferrite Brad | L1, L2, L3, L4, L5, L6, L7 | 3000mA | 25% | 120R | 7
CAP-CER-14 | MURATA | GRM1555C1H101JA01D | 100pF, Ceramic Capacitor | C187 | 50V | 5% | 100pF | 1
CAP-CER-2 | MURATA | GRM1555C1H220JZ01D | 22pF, Ceramic Capacitor | C169, C189, C190, C726 | 50V | 5% | 22pF | 4
CAP-CER-7 | MURATA | GRM155R60J474KE19 | 0.47uF, Ceramic Capacitor |  | 6.3V | 10% | 0.47uF | 84
CAP-CER-4 | MURATA | GRM155R61H102KA01D | 1000pF, Ceramic Capacitor | C60, C80, C84, C93, C184, C218, C275, C294, C501, C503, C568, C611, C628, C665, C680, C751, C753, C763, C765 | 50V | 10% | 1000pF | 19
CAP-CER-6 | MURATA | GRM155R71E103KA01D | 0.01uF, Ceramic Capacitor |  | 25V | 10% | 0.01uF | 109
CAP-CER-8 | MURATA | GRM21BR61C105KA01L | 1uF, Ceramic Capacitor | C37, C40, C41, C51, C52 | 16V | 10% | 1uF | 5
CAP-CER-3 | MURATA | GRM21BR61E475KA12K | 4.7uF, Ceramic Capacitor | C39, C43, C45, C50, C56, C176, C177, C185, C205, C216, C262, C268, C272, C512, C522, C532, C533, C542, C543, C566, C572, C582, C592, C593, C602, C603, C626, C661, C730, C733, C735, C737, C739, C742, C745, C747, C749 | 25V | 10% | 4.7uF | 37
CAP-CER-5 | MURATA | GRM32DR61E106KA12L | 10uF, Ceramic Capacitor | C7, C9, C10, C12, C15, C16, C21, C24, C163, C217, C220, C221, C224, C234, C244, C254, C274, C280, C281, C289, C487, C491, C567, C570, C571, C612, C619, C627, C630, C631, C633, C634, C641, C651, C662, C667, C668, C679, C685, C686, C694 | 25V | 10% | 10uF | 41
CAP-CER-9 | MURATA | GRM32ER61E226ME15L | 22uF, Ceramic Capacitor | C2, C4, C18, C20, C27, C29, C33, C35 | 25V | 20% | 22uF | 8
IC-REG-8 | National Semiconductor | LP2985IM5-3.8 | Micropower, 150mA Low-Noise Ultra Low-Dropout CMOS 3.8V Voltage Regulator in SOT23-5 | U14 |  |  |  | 1
ELMECH-ESD-1 | NXP | PRTR5V0U2AX | Ultra-low capacitance, double rail-to-rail, ESD protection diode in a SOT143B package | SP3 |  |  |  | 1
ELMECH-SW-0 | OMRON | A6S-4101-H | 4-Input, Surface mount, DIP Switch | S2, S3 |  |  |  | 2
CAP-ELC-1 | PANASONIC-ECG | EEE1EA331UP | 330uF, Surface Mount, Radial, Aluminium Electrolytic Capacitor | C1, C17, C26, C30 | 25V | 20% | 330uF | 4
CAP-ELC-0 | PANASONIC-ECG | EEUFC1E102S | 1000uF, Aluminium Electrolytic Capacitor | C32 | 25V | 20% | 1000uF | 1
IC-LOG-5 | PERICOM | PI5A3157CEX | Low voltage SPDT Analogue Switch | U31, U37, U39, U52, U53, U83, U87, U89, U90, U91 |  |  |  | 10
RES-TF-29 | ROYALOHM | 0402WAF1962T1E | 19K6, 1.1mm x 0.5mm, Thick Film Resistor | R23, R46 | 0.1W | 1% | 19K6 | 2
RES-TF-34 | ROYALOHM | 0402WAF2371T1E | 2K37, 1.1mm x 0.5mm, Thick Film Resistor | R5 | 0.1W | 1% | 2K37 | 1
RES-TF-23 | ROYALOHM | 0402WAF4751T1E | 4K75, 1.1mm x 0.5mm, Thick Film Resistor | R14 | 0.1W | 1% | 4K75 | 1
RES-TF-33 | ROYALOHM | 0402WAF6342T1E | 63K4, 1.1mm x 0.5mm, Thick Film Resistor | R29, R33, R429, R445 | 0.1W | 1% | 63K4 | 4
RES-TF-44 | ROYALOHM | 0402WAJ8061T1E | 6K49, 1.1mm x 0.5mm, Thick Film Resistor | R18 | 0.0625W | 1% | 6K49 | 1
RES-TF-43 | ROYALOHM | 0402WAJ8061T1E | 8K06, 1.1mm x 0.5mm, Thick Film Resistor | R3, R10 | 0.0625W | 1% | 8k06 | 2
RES-TF-0 | ROYALOHM | 0402WG00000T1E | 0R, 1.1mm x 0.5mm, Thick Film Resistor |  | 0.0625W | 0% | 0R | 130
RES-TF-14 | ROYALOHM | 0402WGF0101T1E | 100R, 1.1mm x 0.5mm, Thick Film Resistor | R65, R66, R174, R177, R178, R179, R180, R190, R228, R268, R381, R420, R427, R439, R442 | 0.0625W | 1% | 100R | 15
RES-TF-20 | ROYALOHM | 0402WGF0103T1E | 10K, 1.1mm x 0.5mm, Thick Film Resistor | R41, R53, R135, R136, R249, R348, R421, R428, R440, R443 | 0.0625W | 1% | 10K | 10
RES-TF-3 | ROYALOHM | 0402WGF0123T1E | 12K, 1.1mm x 0.5mm, Thick Film Resistor | R129 | 0.0625W | 1% | 12K | 1
RES-TF-19 | ROYALOHM | 0402WGF0201T1E | 200R, 1.1mm x 0.5mm, Thick Film Resistor | R51, R61, R82, R83, R123, R224, R418, R422, R423, R424, R425, R431, R432, R433, R434, R453, R454, R455, R456, R457 | 0.0625W | 1% | 200R | 20
RES-TF-1 | ROYALOHM | 0402WGF0331T1E | 330R, 1.1mm x 0.5mm, Thick Film Resistor | R37 | 0.0625W | 1% | 330R | 1
RES-TF-2 | ROYALOHM | 0402WGF0342T1E | 3K4, 1.1mm x 0.5mm, Thick Film Resistor | R128 | 0.0625W | 1% | 3K4 | 1
RES-TF-51 | ROYALOHM | 0402WGF1003T1E | 100K, 1.1mm x 0.5mm, Thick Film Resistor | R262, R347 | 0.0625W | 1% | 100K | 2
RES-TF-53 | ROYALOHM | 0402WGF1004T1E | 1M, 1.1mm x 0.5mm, Thick Film Resistor | R368 | 0.0625W | 1% | 1M | 1
RES-TF-35 | ROYALOHM | 0402WGF1131T1E | 1K13, 1.1mm x 0.5mm, Thick Film Resistor | R6 | 0.0625W | 1% | 1K13 | 1
RES-TF-28 | ROYALOHM | 0402WGF1150T1E | 1K15, 1.1mm x 0.5mm, Thick Film Resistor | R19, R349 | 0.0625W | 1% | 1K15 | 2
RES-TF-49 | ROYALOHM | 0402WGF1201T1E | 1K2, 1.1mm x 0.5mm, Thick Film Resistor | R52, R59, R73 | 0.0625W | 1% | 1K2 | 3
RES-TF-50 | ROYALOHM | 0402WGF1501T1E | 1K5, 1.1mm x 0.5mm, Thick Film Resistor | R39, R40 | 0.0625W | 1% | 1K5 | 2
RES-TF-30 | ROYALOHM | 0402WGF1742T1E | 17K4, 1.1mm x 0.5mm, Thick Film Resistor | R26, R80 | 0.0625W | 1% | 17K4 | 2
RES-TF-15 | ROYALOHM | 0402WGF2490T1E | 249R, 1.1mm x 0.5mm, Thick Film Resistor | R122, R320, R321, R371, R372, R437, R444, R449 | 0.0625W | 1% | 249R | 8
RES-TF-36 | ROYALOHM | 0402WGF2K49T1E | 2K49, 1.1mm x 0.5mm, Thick Film Resistor | R7 | 0.0625W | 1% | 2K49 | 1
RES-TF-52 | ROYALOHM | 0402WGF3302T1E | 33K, 1.1mm x 0.5mm, Thick Film Resistor | R369 | 0.0625W | 1% | 33K | 1
RES-TF-26 | ROYALOHM | 0402WGF3751T1E | 3K57, 1.1mm x 0.5mm, Thick Film Resistor | R17 | 0.0625W | 1% | 3K74 | 1
RES-TF-37 | ROYALOHM | 0402WGF4531T1E | 4K53, 1.1mm x 0.5mm, Thick Film Resistor | R8 | 0.0625W | 1% | 4K53 | 1
RES-TF-47 | ROYALOHM | 0402WGF4700T1E | 470R, 1.1mm x 0.5mm, Thick Film Resistor | R79 | 0.0625W | 1% | 470R | 1
RES-TF-13 | ROYALOHM | 0402WGF4991T1E | 4K99, 1.1mm x 0.5mm, Thick Film Resistor | R9, R245, R414 | 0.0625W | 1% | 4K99 | 3
RES-TF-10 | ROYALOHM | 0402WGF499JT1E | 49R9, 1.1mm x 0.5mm, Thick Film Resistor |  | 0.0625W | 1% | 49R9 | 59
RES-TF-48 | ROYALOHM | 0402WGF7680T1E | 768R, 1.1mm x 0.5mm, Thick Film Resistor | R38, R56 | 0.0625W | 1% | 768R | 2
RES-TF-8 | ROYALOHM | 0402WGJ0102T1E | 1K, 1.1mm x 0.5mm, Thick Film Resistor | R81, R93, R95, R111, R115, R140, R145, R146, R238, R250, R251, R257, R450, R452, R491 | 0.0625W | 5% | 1K | 15
RES-TF-5 | ROYALOHM | 0402WGJ0103T1E | 10K, 1.1mm x 0.5mm, Thick Film Resistor |  | 0.0625W | 5% | 10K | 78
RES-TF-7 | ROYALOHM | 0402WGJ0332T1E | 3K3, 1.1mm x 0.5mm, Thick Film Resistor |  | 0.0625W | 5% | 3K3 | 71
RES-TF-24 | ROYALOHM | 0402WGJ330KT1E | 3R3, 1.1mm x 0.5mm, Thick Film Resistor | R151, R152, R153, R154, R155, R156, R157, R158, R159, R160, R161, R162, R163, R164, R165, R166, R167, R168, R169, R170, R201, R202, R203, R204, R205, R206, R215, R216, R217, R218, R220, R221, R222, R285, R286, R287 | 0.0625W | 5% | 3R3 | 36
RES-TF-39 | ROYALOHM | 4D02WGJ499JB1E | 4-Wide, Isolated, Thick Film Resistor Network | RP1, RP2, RP3, RP4, RP5, RP6, RP7, RP8, RP9, RP10, RP11, RP12, RP13, RP14, RP15, RP16, RP17, RP18, RP19, RP20, RP21, RP22, RP23, RP24, RP25, RP26 | 0.0625W | 1% | 49R9 | 26
CONN-PCB-23 | SAMTEC | QMSS-064-06.75-L-D-A-DP | Shielded, 64-Differential Pair, Rugged High-Speed Terminal Strip, 0.635mm Pitch, | J7, J8 |  |  |  | 2
CONN-PCB-16 | SAMTEC | TSM-107-01-TM-DV-P | 2x7, 2.54 mm Pitch, Male Header | P7, P16 |  |  |  | 2
CONN-PCB-11 | SAMTEC | TSM-108-01-TM-DV-P | 2x8, 2.54 mm Pitch, Male Header | P17 |  |  |  | 1
IC-MEM-0 | Spansion | S29GL01GP11FFIR10 | 3V, 1 Gigabit NOR Flash | U30 |  |  |  | 1
RES-MF-0 | STACKPOLE | CSS27250.00025FRDKR-ND | 0.25 milliohm, Power Metal Foil;, Sense Resistor | R27 | 4W | 1% | 0R00025 | 1
CAP-CER-11 | TAIYO YUDEN | AMK105BJ475MV-F | 4.7uF, Ceramic Capacitor | C318, C319, C320, C321, C322, C323, C324, C325, C365, C366, C367, C369, C377, C379, C381, C383, C386, C390, C392, C393, C397, C399, C401, C404, C409, C411, C413, C416, C419 | 4V | 20% | 4.7uF | 29
IC-LOG-15 | Texas Instruments | CDCU877RHA | SSTL Zero-Delay Clock Buffer | U40 |  |  |  | 1
IC-AMP-0 | Texas Instruments | INA333AIDGKR | Micro-Power, Zero-Drift, Rail-to-Rail Out Instrumentation Amplifier | U19, U20, U24, U27, U28 |  |  |  | 5
IC-REG-0 | Texas Instruments | PTH08T210WAD | 30-A, 5.5V-14-V INPUT, NON-ISOLATED, WIDE OUTPUT ADJUST, POWER MODULE WITH TURBOTRANS | U8 |  |  |  | 1
IC-REG-1 | Texas Instruments | PTH08T220WAD | 16-A, 4.5-V to 14-V INPUT, NON-ISOLATED, WIDE-OUTPUT, ADJUSTABLE POWER MODULE WITH TurboTrans | U6 |  |  |  | 1
IC-REG-2 | Texas Instruments | PTH08T240WAD | 10-A, 4.5-V to 14-V INPUT, NON-ISOLATED, WIDE-OUTPUT, ADJUSTABLE POWER MODULE WITH TurboTrans | U3 |  |  |  | 1
IC-REG-3 | Texas Instruments | PTH08T250WAD | 50-A, 4.5-V to 14-V INPUT, NON-ISOLATED, WIDE-OUTPUT, ADJUSTABLE POWER MODULE WITH TurboTrans | U9 |  |  |  | 1
IC-LOG-8 | Texas Instruments | SN65LVDT2DBV | Single High-Speed Differential Line Receiver with ODT | U71 |  |  |  | 1
IC-LOG-1 | Texas Instruments | SN74AUC1G04DBV | Single Inverter Gate | U74 |  |  |  | 1
IC-LOG-11 | Texas Instruments | SN74AVC16T245DGG | 16-BIT DUAL-SUPPLY BUS TRANSCEIVER WITH CONFIGURABLE VOLTAGE TRANSLATION AND 3-STATE OUTPUTS | U78, U81 |  |  |  | 2
IC-LOG-12 | Texas Instruments | SN74AVC20T245DGG | 20-Bit Dual-Supply Bus Transceivers with Configurable Voltage Translation and 3-State Outputs | U76, U80 |  |  |  | 2
IC-LOG-10 | Texas Instruments | SN74AVC8T245PW | 8-BIT DUAL-SUPPLY BUS TRANSCEIVER WITH CONFIGURABLE VOLTAGE TRANSLATION AND 3-STATE OUTPUTS | U68 |  |  |  | 1
IC-LOG-13 | Texas Instruments | SN74AVCH1T45DBV | Single-Bit Dual Supply Bus Transceiver with Configurable Voltage Translation and 3-State Outputs | U73, U75 |  |  |  | 2
IC-LOG-2 | Texas Instruments | SN74LV21APW | Dual 4-Input Positive-AND Gates | U25 |  |  |  | 1
IC-LOG-3 | Texas Instruments | SN74LVC1G10DBV | Single 3-input Positive-NAND gate | U48, U49, U65, U66 |  |  |  | 4
IC-LOG-4 | Texas Instruments | SN74LVC244ADW | Octal Buffer/Drive with 3-State Outputs | U77, U79, U82 |  |  |  | 3
IC-AMP-2 | Texas Instruments | THS3091DDA | HIGH VOLTAGE, LOW-DISTORTION, CURRENT-FEEDBACK AMPLIFIERS | U70 |  |  |  | 1
IC-REG-6 | Texas Instruments | TPS51100DGQ | 3A Sink/Source Regulator | U41, U59, U62, U63 |  |  |  | 4
IC-REG-5 | Texas Instruments | TPS74401RGW | 3.0A Ultra-LDO with Programmable Soft-Start | U4, U5, U7 |  |  |  | 3
IC-LOG-6 | Texas Instruments | TS5A3159ADBV | 6-pin 1 Ohm analogue switch | U47 |  |  |  | 1
CONN-PCB-3 | TYCO | 1932000-1 | 240-pin DDR3 DIMM Socket | J6 |  |  |  | 1
CONN-PCB-9 | TYCO | 5767054-1 | TRACE Debug Interface Receptacle | P2 |  |  |  | 1
CONN-PCB-8 | TYCO | 6367550-5 | ZDOK+ Host Board Connector | P10, P11 |  |  |  | 2
CAP-CER-1 | VENKEL | C0402X7R160-104KN | 0.1uF, Ceramic Capacitor |  | 16V | 10% | 0.1uF | 356
CAP-TAN-3 | VISHAY | 594D337X0016R2T | 330uF, Solid Tantalum Chip Capacitor | C31, C36, C671, C672 | 16V | 20% | 330uF | 4
RES-WW-0 | VISHAY | AC05000001009JLB00 | 10R, Cemented Wire Round Resistor | R13 | 5W | 5% | 10R | 1
RES-WW-1 | VISHAY | AC05000001009JLB00 | 56R, Cemented Wire Round Resistor | R16 | 5W | 5% | 56R | 1
RES-MS-2 | VISHAY | WSL25121L000FEA | 1 milliohm, Power Metal Strip, Sense Resistor | R21 | 1W | 1% | 0R001 | 1
RES-MS-1 | VISHAY | WSL25122L000FEA | 2 milliohm, Power Metal Strip, Sense Resistor | R11, R25, R28 | 1W | 1% | 0R002 | 3
RES-MS-0 | VISHAY | WSL25125L000FEA | 5 milliohm, Power Metal Strip, Sense Resistor | R4, R24 | 1W | 1% | 0R005 | 2
IC-PLD-1 | Xilinx | XC2C256-7VQG100C | CoolRunner-II, 1.8V, 256 Macrocell CPLD, 100-Pin VQFP, Pb-Free, Commercial Grade | U46 |  |  |  | 1
IC-PLD-0 | Xilinx | XC6VSX475T-1FFG1759C | Virtex-6 475SXT 1760-pin FPGA | U1 |  |  |  | 1

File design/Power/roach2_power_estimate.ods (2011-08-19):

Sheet: power_calcs
Subsystem | Component | Supply | Parent Supply | TYP Current (mA) | TYP Power (mW) | DES Current (mA) | DES Power (mW) | Reference/Comments
PPC | DRAM | 1V8 | 1V8 | 1280 | 2304 | 1280 | 2304 | Power for DIMM, See micron ddr2 power calculator, 1.8V, 166MHz, does not include clock buffer + registers
 |  | DDR2_VTT | 1V8 | 488.89 | 440 | 488.89 | 440 | Termination of address+control+data
 | FLASH | 3V3 | 3V3 | 30 | 99 | 100 | 330 | Maximum current draw while programming
 | CPLD | 1V8 | 1V8 | 40 | 72 | 40 | 72 | Xilinx CPLD, Icc vs Frequency, F = 100 MHz
 |  | 3V3 | 3V3 | 75 | 247.5 | 75 | 247.5 | Sandisk product manual v1.9
 | CPU | 1V5 | 1V5 | 1615 | 2422.5 | 3410 | 5115 | From AMCC Datasheet (table 16)
 |  | 1V8 | 1V8 | 210 | 378 | 300 | 540 | From AMCC Datasheet (table 16)
 |  | 2V5 | 2V5 | 115 | 287.5 | 570 | 1425 | From AMCC Datasheet (table 16)
 |  | 3V3 | 3V3 | 150 | 495 | 180 | 594 | From AMCC Datasheet (table 16)
 | NET | 1V0 | 1V0 | 250 | 250 | 250 | 250 | From marvell datasheet
 |  | 2V5 | 2V5 | 289 | 722.5 | 289 | 722.5 | From marvell datasheet
QDR | QDR0 | 1V8 | 1V8 | 1170 | 2106 | 1330 | 2394 | From Cypress datasheet @ 400 MHz, full read/write
 |  | QDR_VTT | 1V5 | 345 | 258.75 | 345 | 258.75 | 23 Terminated address+control lines
 |  | 1V5 | 1V5 | 540 | 810 | 540 | 810 | 36 Terminated data lines
 | QDR1 | 1V8 | 1V8 | 1170 | 2106 | 1330 | 2394 | From Cypress datasheet @ 400 MHz, full read/write
 |  | QDR_VTT | 1V5 | 345 | 258.75 | 345 | 258.75 | 23 Terminated address+control lines
 |  | 1V5 | 1V5 | 540 | 810 | 540 | 810 | 36 Terminated data lines
 | QDR2 | 1V8 | 1V8 | 1170 | 2106 | 1330 | 2394 | From Cypress datasheet @ 400 MHz, full read/write
 |  | QDR_VTT | 1V5 | 345 | 258.75 | 345 | 258.75 | 23 Terminated address+control lines
 |  | 1V5 | 1V5 | 540 | 810 | 540 | 810 | 36 Terminated data lines
 | QDR3 | 1V8 | 1V8 | 1170 | 2106 | 1330 | 2394 | From Cypress datasheet @ 400 MHz, full read/write
 |  | QDR_VTT | 1V5 | 345 | 258.75 | 345 | 258.75 | 23 Terminated address+control lines
 |  | 1V5 | 1V5 | 540 | 810 | 540 | 810 | 36 Terminated data lines
V6 | FPGA | 1V0 | 1V0 | 43802 | 43802 | 48182.2 | 48182.2 | Calculated using Xilinx virtex-6 power estimator (expected), worst case = +10%
 |  | 1V5 | 1V5 | 3925 | 5887.5 | 4317.5 | 6476.25
 |  | 2V5 | 2V5 | 2130 | 5325 | 2343 | 5857.5
 |  | MGT_1V0 | 1V5 | 1980 | 1980 | 3900 | 3900
 |  | MGT_1V2 | 1V5 | 2390 | 2868 | 2600 | 3120
 | DRAM | 1V5 | 1V5 | 2915.2 | 4372.8 | 2915.2 | 4372.8 | Calculated with micron ddr3 power calculator, dual rank x 8 x 8 bit modules @ 400MHz
 |  | DDR3_VTT | 1V5 | 0 | 0 | 0 | 0
 | NET | 1V0 | 1V0 | 250 | 250 | 250 | 250 | From marvell datasheet
 |  | 2V5 | 2V5 | 289 | 722.5 | 289 | 722.5 | From marvell datasheet
 | ZDOK0 | 5V | 5V | 100 | 500 | 3000 | 15000 | Supplies Rated at 1.5A, typically only one would be fully loaded
 |  | 3V3 | 3V3 | 100 | 330 | 1500 | 4950 | Supplies Rated at 1.5A, typically only one would be fully loaded
 |  | 2V5 | 2V5 | 1200 | 3000 | 1500 | 3750 | Supplies Rated at 1.5A, typically only one would be fully loaded
 |  | 1V8 | 1V8 | 0 | 0 | 1500 | 2700 | Supplies Rated at 1.5A, typically only one would be fully loaded
 | ZDOK1 | 5V | 5V | 100 | 500 | 3000 | 15000 | Supplies Rated at 1.5A, typically only one would be fully loaded
 |  | 3V3 | 3V3 | 100 | 330 | 1500 | 4950 | Supplies Rated at 1.5A, typically only one would be fully loaded
 |  | 2V5 | 2V5 | 1200 | 3000 | 1500 | 3750 | Supplies Rated at 1.5A, typically only one would be fully loaded
 |  | 1V8 | 1V8 | 0 | 0 | 1500 | 2700 | Supplies Rated at 1.5A, typically only one would be fully loaded
 | MGTB_0 | 3V3 | 3V3 | 1750 | 5775 | 3500 | 11550 | Enough power for 8 SFP+ ports at 1W per port; most probably would require additional ATX power
 |  | 1V5 | 1V5 | 400 | 600 | 400 | 600
 | MGTB_1 | 3V3 | 3V3 | 1750 | 5775 | 3500 | 11550
 |  | 1V5 | 1V5 | 400 | 600 | 400 | 600
 |  |  |  |  | 106034.8 |  | 175872.25
 | Totals |  | 1V0 | 1V5 | 1V8 | 2V5 | 3V3 | 5V
DRAM | 1V8 | 1V8 | 0 | 0 | 1280 | 0 | 0 | 0 | 2304 | 3184 | 12480
 | DDR2_VTT | 1V8 | 0 | 0 | 488.89 | 0 | 0 | 0 | 880
FLASH | 3V3 | 3V3 | 0 | 0 | 0 | 0 | 100 | 0 | 330 | 330
CPLD | 1V8 | 1V8 | 0 | 0 | 40 | 0 | 0 | 0 | 72 | 319.5
 | 3V3 | 3V3 | 0 | 0 | 0 | 0 | 75 | 0 | 247.5
CPU | 1V5 | 1V5 | 0 | 3410 | 0 | 0 | 0 | 0 | 5115 | 7674
 | 1V8 | 1V8 | 0 | 0 | 300 | 0 | 0 | 0 | 540
 | 2V5 | 2V5 | 0 | 0 | 0 | 570 | 0 | 0 | 1425
 | 3V3 | 3V3 | 0 | 0 | 0 | 0 | 180 | 0 | 594
NET | 1V0 | 1V0 | 250 | 0 | 0 | 0 | 0 | 0 | 250 | 972.5
 | 2V5 | 2V5 | 0 | 0 | 0 | 289 | 0 | 0 | 722.5
QDR0 | 1V8 | 1V8 | 0 | 0 | 1330 | 0 | 0 | 0 | 2394 | 3721.5 | 167597.25
 | QDR_VTT | 1V5 | 0 | 345 | 0 | 0 | 0 | 0 | 517.5
 | 1V5 | 1V5 | 0 | 540 | 0 | 0 | 0 | 0 | 810
QDR1 | 1V8 | 1V8 | 0 | 0 | 1330 | 0 | 0 | 0 | 2394 | 3721.5
 | QDR_VTT | 1V5 | 0 | 345 | 0 | 0 | 0 | 0 | 517.5
 | 1V5 | 1V5 | 0 | 540 | 0 | 0 | 0 | 0 | 810
QDR2 | 1V8 | 1V8 | 0 | 0 | 1330 | 0 | 0 | 0 | 2394 | 3721.5
 | QDR_VTT | 1V5 | 0 | 345 | 0 | 0 | 0 | 0 | 517.5
 | 1V5 | 1V5 | 0 | 540 | 0 | 0 | 0 | 0 | 810
QDR3 | 1V8 | 1V8 | 0 | 0 | 1330 | 0 | 0 | 0 | 2394 | 3721.5
 | QDR_VTT | 1V5 | 0 | 345 | 0 | 0 | 0 | 0 | 517.5
 | 1V5 | 1V5 | 0 | 540 | 0 | 0 | 0 | 0 | 810
FPGA | 1V0 | 1V0 | 48182.2 | 0 | 0 | 0 | 0 | 0 | 48182.2 | 70265.95
 | 1V5 | 1V5 | 0 | 4317.5 | 0 | 0 | 0 | 0 | 6476.25
 | 2V5 | 2V5 | 0 | 0 | 0 | 2343 | 0 | 0 | 5857.5
 | MGT_1V0 | 1V5 | 0 | 3900 | 0 | 0 | 0 | 0 | 5850
 | MGT_1V2 | 1V5 | 0 | 2600 | 0 | 0 | 0 | 0 | 3900
DRAM | 1V5 | 1V5 | 0 | 2915.2 | 0 | 0 | 0 | 0 | 4372.8 | 4372.8
 | DDR3_VTT | 1V5 | 0 | 0 | 0 | 0 | 0 | 0 | 0
NET | 1V0 | 1V0 | 250 | 0 | 0 | 0 | 0 | 0 | 250 | 972.5
 | 2V5 | 2V5 | 0 | 0 | 0 | 289 | 0 | 0 | 722.5
ZDOK0 | 5V | 5V | 0 | 0 | 0 | 0 | 0 | 3000 | 15000 | 26400
 | 3V3 | 3V3 | 0 | 0 | 0 | 0 | 1500 | 0 | 4950
 | 2V5 | 2V5 | 0 | 0 | 0 | 1500 | 0 | 0 | 3750
 | 1V8 | 1V8 | 0 | 0 | 1500 | 0 | 0 | 0 | 2700
ZDOK1 | 5V | 5V | 0 | 0 | 0 | 0 | 0 | 3000 | 15000 | 26400
 | 3V3 | 3V3 | 0 | 0 | 0 | 0 | 1500 | 0 | 4950
 | 2V5 | 2V5 | 0 | 0 | 0 | 1500 | 0 | 0 | 3750
 | 1V8 | 1V8 | 0 | 0 | 1500 | 0 | 0 | 0 | 2700
MGTB_0 | 3V3 | 3V3 | 0 | 0 | 0 | 0 | 3500 | 0 | 11550 | 12150
 | 1V5 | 1V5 | 0 | 400 | 0 | 0 | 0 | 0 | 600
MGTB_1 | 3V3 | 3V3 | 0 | 0 | 0 | 0 | 3500 | 0 | 11550 | 12150
 | 1V5 | 1V5 | 0 | 400 | 0 | 0 | 0 | 0 | 600
 |  | Total Current | 48682.2 | 21482.7 | 10428.89 | 6491 | 10355 | 6000
 |  | Total Power
 |  | Rating | 50 | 25 | 15 | 10
 |  |  | 3V3 | 5V | 12V
 | ATX supply Load (Amps) |  | 10355 | 17454.64 | 6399.92
 | ATX supply Load (W) |  | 34171.5 | 87273.18 | 76798.98 | 198243.66
 | Totals |  | 1V0 | 1V5 | 1V8 | 2V5 | 3V3 | 5V
DRAM | 1V8 | 1V8 | 0 | 0 | 1280 | 0 | 0 | 0 | 2304 | 3184 | 8158
 | DDR2_VTT | 1V8 | 0 | 0 | 488.89 | 0 | 0 | 0 | 880
FLASH | 3V3 | 3V3 | 0 | 0 | 0 | 0 | 30 | 0 | 99 | 99
CPLD | 1V8 | 1V8 | 0 | 0 | 40 | 0 | 0 | 0 | 72 | 319.5
 | 3V3 | 3V3 | 0 | 0 | 0 | 0 | 75 | 0 | 247.5
CPU | 1V5 | 1V5 | 0 | 1615 | 0 | 0 | 0 | 0 | 2422.5 | 3583
 | 1V8 | 1V8 | 0 | 0 | 210 | 0 | 0 | 0 | 378
 | 2V5 | 2V5 | 0 | 0 | 0 | 115 | 0 | 0 | 287.5
 | 3V3 | 3V3 | 0 | 0 | 0 | 0 | 150 | 0 | 495
NET | 1V0 | 1V0 | 250 | 0 | 0 | 0 | 0 | 0 | 250 | 972.5
 | 2V5 | 2V5 | 0 | 0 | 0 | 289 | 0 | 0 | 722.5
QDR0 | 1V8 | 1V8 | 0 | 0 | 1170 | 0 | 0 | 0 | 2106 | 3433.5 | 101058.8
 | QDR_VTT | 1V5 | 0 | 345 | 0 | 0 | 0 | 0 | 517.5
 | 1V5 | 1V5 | 0 | 540 | 0 | 0 | 0 | 0 | 810
QDR1 | 1V8 | 1V8 | 0 | 0 | 1170 | 0 | 0 | 0 | 2106 | 3433.5
 | QDR_VTT | 1V5 | 0 | 345 | 0 | 0 | 0 | 0 | 517.5
 | 1V5 | 1V5 | 0 | 540 | 0 | 0 | 0 | 0 | 810
QDR2 | 1V8 | 1V8 | 0 | 0 | 1170 | 0 | 0 | 0 | 2106 | 3433.5
 | QDR_VTT | 1V5 | 0 | 345 | 0 | 0 | 0 | 0 | 517.5
 | 1V5 | 1V5 | 0 | 540 | 0 | 0 | 0 | 0 | 810
QDR3 | 1V8 | 1V8 | 0 | 0 | 1170 | 0 | 0 | 0 | 2106 | 3433.5
 | QDR_VTT | 1V5 | 0 | 345 | 0 | 0 | 0 | 0 | 517.5
 | 1V5 | 1V5 | 0 | 540 | 0 | 0 | 0 | 0 | 810
FPGA | 1V0 | 1V0 | 43802 | 0 | 0 | 0 | 0 | 0 | 43802 | 61569.5
 | 1V5 | 1V5 | 0 | 3925 | 0 | 0 | 0 | 0 | 5887.5
 | 2V5 | 2V5 | 0 | 0 | 0 | 2130 | 0 | 0 | 5325
 | MGT_1V0 | 1V5 | 0 | 1980 | 0 | 0 | 0 | 0 | 2970
 | MGT_1V2 | 1V5 | 0 | 2390 | 0 | 0 | 0 | 0 | 3585
DRAM | 1V5 | 1V5 | 0 | 2915.2 | 0 | 0 | 0 | 0 | 4372.8 | 4372.8
 | DDR3_VTT | 1V5 | 0 | 0 | 0 | 0 | 0 | 0 | 0
NET | 1V0 | 1V0 | 250 | 0 | 0 | 0 | 0 | 0 | 250 | 972.5
 | 2V5 | 2V5 | 0 | 0 | 0 | 289 | 0 | 0 | 722.5
ZDOK0 | 5V | 5V | 0 | 0 | 0 | 0 | 0 | 100 | 500 | 3830
 | 3V3 | 3V3 | 0 | 0 | 0 | 0 | 100 | 0 | 330
 | 2V5 | 2V5 | 0 | 0 | 0 | 1200 | 0 | 0 | 3000
 | 1V8 | 1V8 | 0 | 0 | 0 | 0 | 0 | 0 | 0
ZDOK1 | 5V | 5V | 0 | 0 | 0 | 0 | 0 | 100 | 500 | 3830
 | 3V3 | 3V3 | 0 | 0 | 0 | 0 | 100 | 0 | 330
 | 2V5 | 2V5 | 0 | 0 | 0 | 1200 | 0 | 0 | 3000
 | 1V8 | 1V8 | 0 | 0 | 0 | 0 | 0 | 0 | 0
MGTB_0 | 3V3 | 3V3 | 0 | 0 | 0 | 0 | 1750 | 0 | 5775 | 6375
 | 1V5 | 1V5 | 0 | 400 | 0 | 0 | 0 | 0 | 600
MGTB_1 | 3V3 | 3V3 | 0 | 0 | 0 | 0 | 1750 | 0 | 5775 | 6375
 | 1V5 | 1V5 | 0 | 400 | 0 | 0 | 0 | 0 | 600
 |  | Total Current | 44302 | 17165.2 | 6698.89 | 5223 | 3955 | 200
 |  | Total Power
 |  | Rating | 50 | 25 | 15 | 10
 |  |  | 3V3 | 5V | 12V
 | ATX supply Load (Amps) |  | 3955 | 10624 | 4849.8
 | ATX supply Load (W) |  | 13051.5 | 53120 | 58197.64 | 124369.14

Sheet: sense_res
 |  | target power | 0.25000 |  | TargetV | 1.20000
supply | current | vdrop | rsense(calculated) | rsense (chosen) | Actual power | required gain | chosen gain
12.00000 | 6.50000 | 0.03846 | 0.00592 | 0.00500 | 0.21125 | 202.80000 | 200.00000
5.00000 | 10.50000 | 0.02381 | 0.00227 | 0.00200 | 0.22050 | 529.20000 | 500.00000
3.30000 | 10.50000 | 0.02381 | 0.00227 | 0.00200 | 0.22050 | 529.20000 | 500.00000
2.50000 | 6.50000 | 0.03846 | 0.00592 | 0.00500 | 0.21125 | 202.80000 | 200.00000
1.80000 | 10.50000 | 0.02381 | 0.00227 | 0.00200 | 0.22050 | 529.20000 | 500.00000
1.50000 | 22.00000 | 0.01136 | 0.00052 | 0.00100 | 0.48400 | 2323.20000 | 1000.00000
1.00000 | 45.00000 | 0.00556 | 0.00012 | 0.00025 | 0.50625 | 9720.00000 | 1000.00000

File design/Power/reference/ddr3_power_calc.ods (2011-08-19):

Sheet: Title
File Name | : | DDR3_Power_Calc.XLS
Revision | : | 0.1
Date | : | March 13, 2007
E-Mail | : | dramsupport@micron.com
Company | : | Micron Technology, Inc.
Description | : | Calculates the power consumed by a DDR3 SDRAM based on system use parameters and the device data sheet.
Limitations | :
Notes | :
Disclaimer | : | THIS SPREADSHEET IS FOR ESTIMATING PURPOSES ONLY. ANY INFORMATION PROVIDED HEREIN IS PROVIDED "AS IS" AND WITHOUT WARRANTIES OF ANY KIND. MICRON WARRANTS ONLY THAT ITS PRODUCTS COMPLY WITH MICRON'S SPECIFICATION SHEET FOR THE PRODUCT AT THE TIME OF DELIVERY; PROVIDED THAT DEVIATIONS FROM SPECIFICATIONS WHICH DO NOT MATERIALLY AFFECT FORM, FIT OR FUNCTION OF SUCH PRODUCT IN THE SYSTEM AND CONFIGURATION IN OR FOR WHICH IT IS INITIALLY INSTALLED OR QUALIFIED BY CUSTOMER SHALL NOT BE DEEMED TO CONSTITUTE FAILURE TO COMPLY WITH SUCH SPECIFICATIONS.
 |  | SEE MICRON'S STANDARD TERMS AND CONDITIONS OF SALE FOR COMPLETE WARRANTY DETAILS.
 |  | Copyright © 2007 Micron Semiconductor Products, Inc.
 |  | All rights reserved.

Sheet: Instructions
Instructions for Use
 | DDR3 Spec tab (ALL MUST BE VERIFIED FOR A SPECIFIC DRAM DATA SHEET)
 |  | Inputs are required for all densities and speed grades that may be chosen.
 |  | Enter VDD tolerance range in rows 6–7.
 |  | Enter IDD values for the speed grade under investigation in rows 9–26. Note that there are entries for both x4/x8 devices, as well as x16. Also note the two separate entries for IDD3P, depending on the mode register setting.
 |  | Timing restrictions in rows 28–36 are entered from the data sheet. These determine the test conditions for the IDD values and restrictions of normal device operation.
 | DDR3 Config Spec tab (ALL MUST BE ENTERED TO IDENTIFY DRAM TO BE USED FOR POWER CALCULATION)
 |  | Row 7 selects which DRAM density.
 |  | Row 8 selects the number of DQs.
 |  | Row 9 selects the starting speed grade.
 |  | Row 12 selects whether fast or slow exit is used for power-down exit.
 | Usage Conditions tab (ALL MUST BE ENTERED FOR SPECIFIC SYSTEM)
 |  | Row 7 is the actual VDD the system is operating at. It is usually set to nominal conditions.
 |  | Row 8 is the clock rate the DRAM is operating at. This is one half of the data rate.
 |  | Row 9 is the burst length programmed in the mode register. (The model does not calculate power if burst interrupt is utilized.)
 |  | Row 10 is the amount of power that is drawn per output while driving data. This is system-dependent and must be calculated. The value may be approximated with a DC calculation or more accurately determined using SPICE models.
 |  | Row 11 is the amount of power that is drawn per output while terminating write data to itself. This is system-dependent and must be calculated. The value may be approximated with a DC calculation or more accurately determined using SPICE models.
 |  | Row 12 is the amount of power that is drawn per DQ while terminating read data going to a different DRAM. This is system-dependent and must be calculated. The value may be approximated with a DC calculation or more accurately determined using SPICE models.
 |  | Row 13 is the amount of power that is drawn per DQ while terminating write data going to a different DRAM. This is system-dependent and must be calculated. The value may be approximated with a DC calculation or more accurately determined using SPICE models.
 |  | Row 15 is the time when all banks are in a precharged state. This is the amount of time when no bank has been activated.
 |  | Row 16 is the percentage of time that all that banks are precharged when the device is in power-down state. This is the percentage of time when the DRAM is using IDD2P vs. IDD2F.
 |  | Row 17 is the percentage of DRAM active time when CKE is LOW and the device is in the power-down state. This is the percentage of active time when the DRAM is using IDD3P current vs. IDD3N.
 |  | Row 19 is the average time between ACT commands to the DRAM. Under IDD0 or IDD1 conditions, this would be equal to tRC. If the DRAM is in interleaving bursts, it may be less than tRC. This value is now calculated off of page hit rate. Entering a number here will override the automatic calculation.
 |  | Row 21 is the percentage of clocks that data is read from the DRAM. This would be equal to the average read bandwidth divided by peak read bandwidth.
 |  | Row 22 is the percentage of clocks that data is written to the DRAM. This would be equal to the average read bandwidth divided by peak read bandwidth.
 |  | Row 23 is the page hit rate. 0% means there are no page hits (i.e., one read/write per each activate).
 |  | Row 24 is the percentage of clock cycles the DRAM under investigation is terminating read data from another device. It does not include time when a different DRAM on the bus may be terminating data.
 |  | Row 25 is the percentage of clock cycles the DRAM under investigation is terminating write data from another device. It does not include time when a different DRAM on the bus may be terminating data.
 | Power Calcs tab
 |  | No inputs are required for this tab. It contains some of the detail calculations that provide information into the Summary tab. It can be used as a reference for further understanding the calculator, or you may jump straight to the Summary page for the final answer.
 | Summary tab
 |  | No inputs are required for this tab. It contains a summary of the power used by the DRAM. The power is broken out between: — Power to read/write data to and from the DRAM — Power to activate the rows — Background power for standby modes and refresh

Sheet: DDR3 Spec
 |  |  | 1Gb |  |  |  |  |  |  | 2Gb |  |  |  |  |  |  | 4Gb |  |  |  |  |  |  | TBD
Parameter | Condition | Condition | -15 | -15E | -15F | -187 | -187E | -25 | -25E | -15 | -15E | -15F | -187 | -187E | -25 | -25E | -15 | -15E | -15F | -187 | -187E | -25 | -25E | -15 | -15E | -15F | -187 | -187E | -25 | -25E
 | Maximum VDD |  | 1.58 | 1.58 | 1.58 | 1.58 | 1.58 | 1.58 | 1.58 | 1.58 | 1.58 | 1.58 | 1.58 | 1.58 | 1.58 | 1.58 | 1.58 | 1.58 | 1.58 | 1.58 | 1.58 | 1.58 | 1.58 | 1.58 | 1.58 | 1.58 | 1.58 | 1.58 | 1.58 | 1.58 | V
 | Minimum VDD |  | 1.43 | 1.43 | 1.43 | 1.43 | 1.43 | 1.43 | 1.43 | 1.43 | 1.43 | 1.43 | 1.43 | 1.43 | 1.43 | 1.43 | 1.43 | 1.43 | 1.43 | 1.43 | 1.43 | 1.43 | 1.43 | 1.43 | 1.43 | 1.43 | 1.43 | 1.43 | 1.43 | 1.43 | V
IDD0 | Maximum active precharge current | x4/x8 | TBD | TBD | 125 | TBD | 115 | 95 | TBD | TBD | TBD | 130 | TBD | 120 | 100 | TBD | TBD | TBD | 145 | TBD | 130 | 110 | TBD | TBD | TBD | TBD | TBD | TBD | TBD | TBD | mA
 |  | x16 | TBD | TBD | 155 | TBD | 140 | 120 | TBD | TBD | TBD | TBD | TBD | TBD | TBD | TBD | TBD | TBD | TBD | TBD | TBD | TBD | TBD | TBD | TBD | TBD | TBD | TBD | TBD | TBD | mA
IDD2P (Slow) | Maximum precharge power-down standby current(Slow Exit) | x4/x8 | TBD | TBD | 10 | TBD | 10 | 10 | TBD | TBD | TBD | 10 | TBD | 10 | 10 | TBD | TBD | TBD | 10 | TBD | 10 | 10 | TBD | TBD | TBD | TBD | TBD | TBD | TBD | TBD | mA
 |  | x16 | TBD | TBD | 10 | TBD | 10 | 10 | TBD | TBD | TBD | TBD | TBD | TBD | TBD | TBD | TBD | TBD | TBD | TBD | TBD | TBD | TBD | TBD | TBD | TBD | TBD | TBD | TBD | TBD | mA
IDD2P (Fast) | Maximum precharge power-down standby current(Fast Exit) | x4/x8 | TBD | TBD | 25 | TBD | 25 | 25 | TBD | TBD | TBD | 25 | TBD | 25 | 25 | TBD | TBD | TBD | 25 | TBD | 25 | 25 | TBD | TBD | TBD | TBD | TBD | TBD | TBD | TBD | mA
 |  | x16 | TBD | TBD | 25 | TBD | 25 | 25 | TBD | TBD | TBD | TBD | TBD | TBD | TBD | TBD | TBD | TBD | TBD | TBD | TBD | TBD | TBD | TBD | TBD | TBD | TBD | TBD | TBD | TBD | mA
IDD2N | Maximum precharge standby current | x4/x8 | TBD | TBD | 75 | TBD | 65 | 55 | TBD | TBD | TBD | 70 | TBD | 60 | 50 | TBD | TBD | TBD | 75 | TBD | 65 | 55 | TBD | TBD | TBD | TBD | TBD | TBD | TBD | TBD | mA
 |  | x16 | TBD | TBD | 75 | TBD | 65 | 55 | TBD | TBD | TBD | TBD | TBD | TBD | TBD | TBD | TBD | TBD | TBD | TBD | TBD | TBD | TBD | TBD | TBD | TBD | TBD | TBD | TBD | TBD | mA
IDD3P | Maximum active power-down standby current | x4/x8 | TBD | TBD | 55 | TBD | 45 | 40 | TBD | TBD | TBD | 60 | TBD | 50 | 45 | TBD | TBD | TBD | 60 | TBD | 50 | 45 | TBD | TBD | TBD | TBD | TBD | TBD | TBD | TBD | mA
 |  | x16 | TBD | TBD | 55 | TBD | 45 | 40 | TBD | TBD | TBD | TBD | TBD | TBD | TBD | TBD | TBD | TBD | TBD | TBD | TBD | TBD | TBD | TBD | TBD | TBD | TBD | TBD | TBD | TBD | mA
IDD3N | Maximum active standby current | x4/x8 | TBD | TBD | 90 | TBD | 75 | 60 | TBD | TBD | TBD | 95 | TBD | 80 | 65 | TBD | TBD | TBD | 95 | TBD | 80 | 65 | TBD | TBD | TBD | TBD | TBD | TBD | TBD | TBD | mA
 |  | x16 | TBD | TBD | 95 | TBD | 80 | 65 | TBD | TBD | TBD | TBD | TBD | TBD | TBD | TBD | TBD | TBD | TBD | TBD | TBD | TBD | TBD | TBD | TBD | TBD | TBD | TBD | TBD | TBD | mA
IDD4R | Maximum read burst current | x4/x8 | TBD | TBD | 250 | TBD | 220 | 190 | TBD | TBD | TBD | 255 | TBD | 225 | 195 | TBD | TBD | TBD | 330 | TBD | 295 | 255 | TBD | TBD | TBD | TBD | TBD | TBD | TBD | TBD | mA
 |  | x16 | TBD | TBD | 330 | TBD | 280 | 230 | TBD | TBD | TBD | TBD | TBD | TBD | TBD | TBD | TBD | TBD | TBD | TBD | TBD | TBD | TBD | TBD | TBD | TBD | TBD | TBD | TBD | TBD | mA
IDD4W | Maximum write burst current | x4/x8 | TBD | TBD | 275 | TBD | 240 | 205 | TBD | TBD | TBD | 300 | TBD | 265 | 230 | TBD | TBD | TBD | 390 | TBD | 345 | 300 | TBD | TBD | TBD | TBD | TBD | TBD | TBD | TBD | mA
 |  | x16 | TBD | TBD | 400 | TBD | 350 | 300 | TBD | TBD | TBD | TBD | TBD | TBD | TBD | TBD | TBD | TBD | TBD | TBD | TBD | TBD | TBD | TBD | TBD | TBD | TBD | TBD | TBD | TBD | mA
IDD5A | Maximum burst refresh current | x4/x8 | TBD | TBD | 290 | TBD | 255 | 215 | TBD | TBD | TBD | 320 | TBD | 285 | 245 | TBD | TBD | TBD | 385 | TBD | 340 | 295 | TBD | TBD | TBD | TBD | TBD | TBD | TBD | TBD | mA
 |  | x16 | TBD | TBD | 290 | TBD | 255 | 215 | TBD | TBD | TBD | TBD | TBD | TBD | TBD | TBD | TBD | TBD | TBD | TBD | TBD | TBD | TBD | TBD | TBD | TBD | TBD | TBD | TBD | TBD | mA
 | tCK used for current measurements (see current notes) |  | 1.5 | 1.5 | 1.5 | 1.88 | 1.88 | 2.5 | 2.5 | 1.5 | 1.5 | 1.5 | 1.88 | 1.88 | 2.5 | 2.5 | 1.5 | 1.5 | 1.5 | 1.88 | 1.88 | 2.5 | 2.5 | TBD | TBD | TBD | TBD | TBD | TBD | TBD | ns
tRRD | Minimum activate-to-activate timing (different bank) | x4/x8 | 6 | 6 | 6 | 7.5 | 7.5 | 10 | 10 | 6 | 6 | 6 | 7.5 | 7.5 | 10 | 10 | 6 | 6 | 6 | 7.5 | 7.5 | 10 | 10 | TBD | TBD | TBD | TBD | TBD | TBD | TBD | ns
 |  | x16 | 7.5 | 7.5 | 7.5 | 10 | 10 | 10 | 10 | 7.5 | 7.5 | 7.5 | 10 | 10 | 10 | 10 | 7.5 | 7.5 | 7.5 | 10 | 10 | 10 | 10 | TBD | TBD | TBD | TBD | TBD | TBD | TBD | ns
tRC | Minimum activate-to-activate timing (same bank) |  | 51 | 49.5 | 48 | 52.5 | 50.63 | 52.5 | 50 | 51 | 49.5 | 48 | 52.5 | 50.63 | 52.5 | 50 | 51 | 49.5 | 48 | 52.5 | 50.63 | 52.5 | 50 | TBD | TBD | TBD | TBD | TBD | TBD | TBD | ns
tRAS | tRAS used for IDD0 calculation |  | 36 | 36 | 36 | 37.5 | 37.5 | 37.5 | 37.5 | 36 | 36 | 36 | 37.5 | 37.5 | 37.5 | 37.5 | 36 | 36 | 36 | 37.5 | 37.5 | 37.5 | 37.5 | TBD | TBD | TBD | TBD | TBD | TBD | TBD | ns
tRFC (MIN) | Minimum refresh-to-refresh cycle time |  | 110 | 110 | 110 | 110 | 110 | 110 | 110 | 160 | 160 | 160 | 160 | 160 | 160 | 160 | 300 | 300 | 300 | 300 | 300 | 300 | 300 | TBD | TBD | TBD | TBD | TBD | TBD | TBD | ns
tREFI | Average periodic refresh cycle time |  | 7.8 | 7.8 | 7.8 | 7.8 | 7.8 | 7.8 | 7.8 | 7.8 | 7.8 | 7.8 | 7.8 | 7.8 | 7.8 | 7.8 | 7.8 | 7.8 | 7.8 | 7.8 | 7.8 | 7.8 | 7.8 | TBD | TBD | TBD | TBD | TBD | TBD | TBD | µs
tCK (MIN) | Minimum tCK cycle rate |  | 1.5 | 1.5 | 1.5 | 1.88 | 1.88 | 2.5 | 2.5 | 1.5 | 1.5 | 1.5 | 1.88 | 1.88 | 2.5 | 2.5 | 1.5 | 1.5 | 1.5 | 1.88 | 1.88 | 2.5 | 2.5 | TBD | TBD | TBD | TBD | TBD | TBD | TBD | ns
tCK (MAX) | Maximum tCK cycle rate |  | 3.3 | 3.3 | 3.3 | 3.3 | 3.3 | 3.3 | 3.3 | 3.3 | 3.3 | 3.3 | 3.3 | 3.3 | 3.3 | 3.3 | 3.3 | 3.3 | 3.3 | 3.3 | 3.3 | 3.3 | 3.3 | TBD | TBD | TBD | TBD | TBD | TBD | TBD | ns
Initial numbers are for reference only and must be verified with existing DRAM data sheets for accuracy prior to using the spreadsheet.

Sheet: DDR3 Config
DDR3 SDRAM Configuration |  |  |  | Inputs for DRAM selction are chosen here. The table below is automatically updated from Device Spec Worksheet
 | DRAM Density | 1Gb
 | Number of DQs per DRAM | 8
 | Speed Grade | -187E
 | Mode Register bit 12: Precharge PD Exit Mode
Parameter | Condition | Value | Units
 | Maximum VCC | 1.58 | V
 | Minimum VCC | 1.43 | V
 | Number of DQ strobes (DQS) per DRAM | 2
 | Number of data mask (DM) per DRAM | 1
IDD0 | Maximum active precharge current | 115 | mA
IDD2P | Maximum precharge power-down standby current | 25 | mA
IDD2N | Maximum precharge standby current | 65 | mA | Values are extracted from "DDR3 Spec" tab. Please confirm the numbers in that worksheet are updated prior to use.
IDD3P | Maximum active power-down standby current | 45 | mA
IDD3N | Maximum active standby current | 75 | mA
IDD4R | Maximum read burst current | 220 | mA
IDD4W | Maximum write burst current | 240 | mA
IDD5A | Maximum burst refresh current | 255 | mA
 | tCK used for current measurements (see current notes) | 1.88 | ns
tRRD | Minimum activate-to-activate timing (different bank) | 7.5 | ns
tRC | Minimum activate-to-activate timing (same bank) | 50.63 | ns
tRAS | tRAS used for IDD0 calculation | 37.5 | ns
tRFC (MIN) | Minimum refresh-to-refresh cycle time | 110 | ns
tREFI | Average periodic refresh cycle time | 7.8 | µs
tCK (MIN) | Minimum tCK cycle rate | 1.88 | ns
tCK (MAX) | Maximum tCK cycle rate | 3.3 | ns

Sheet: System Config
 | DRAM Usage Conditions in the System Environment
 | System VDD | 1.5 | V
 | System CK frequency | 400 | MHz
 | Burst length | 8 |  | must be either 4 or 8
PdqRD | DDR3 SDRAM output power per individual DQ on this DRAM | 6.6 | mW | This value is the output driver power per DQ on the DRAM. It is specific to each system design and must be calculated based on the termination scheme.
PdqWR | DDR3 SDRAM termination power per individual DQ during WRITEs to this DRAM | 9.3 | mW | This value is the output driver power per DQ on the DRAM. It is specific to each system design and must be calculated based on the termination scheme.
PdqRDoth | DDR3 SDRAM termination power per individual DQ during READs from other DRAM | 15.2 | mW | This value is the output driver power per DQ on the DRAM. It is specific to each system design and must be calculated based on the termination scheme.
PdqWRoth | DDR3 SDRAM termination power per individual DQ during WRITEs to other DRAM | 13.2 | mW | This value is the output driver power per DQ on the DRAM. It is specific to each system design and must be calculated based on the termination scheme.
BNK_PRE% | The percentage of time that all banks on the DRAM are in a precharged state | 20%
CKE_LO_PRE% | The percentage of the all bank precharge time for which CKE is held LOW | 0%
CKE_LO_ACT% | The percentage of the at least one bank active time for which CKE is held LOW | 0%
PH% | Page hit rate | 50%
RDsch% | The percentage of clock cycles which are outputting read data from the DRAM | 20%
WRsch% | The percentage of clock cycles which are inputting write data to the DRAM | 20%
termRDsch% | The percentage of clock cycles which are terminating read data to another DRAM | 10% |  | must be 0% for a 1-rank system
termWRsch% | The percentage of clock cycles which are terminating write data to another DRAM | 10% |  | must be 0% for a 1-rank system
tRRDsch | The average time between ACT commands to this DRAM (includes ACT to same or different banks in the same DRAM device) | 50.0 | ns |  | This is calculated from page hit rate read/write bus utilization. No entry is necessary.
 | Values that may be updated are shown in green. This will be dependent on how the system accesses the DRAM.

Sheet: Power Calcs
System Derating for 1Gb DDR3 SDRAM (x8, -187E Speed Grade)
Power is calculated after after scaling for VDD. Next, some powers are scaled for frequency effects to derate from test condition to use condition. Finally, these numbers are scaled for actual system usage. All parameters are calculated and require no user input.
 | Worst-Case Power Based on Data Sheet |  |  | Power Derated for System Usage Conditions Input into This Model |  |  | Power Scaled for Actual System Conditions (DRAM Usage, CK Frequency, and VCC)
Background power used during precharge power-down | Pds(PRE_PDN) | 39.4 | mW | Psch(PRE_PDN) | 0.0 | mW | Psys(PRE_PDN) | 0.0 | mW
Background power used during idle standby | Pds(PRE_STBY) | 102.4 | mW | Psch(PRE_STBY) | 20.5 | mW | Psys(PRE_STBY) | 13.9 | mW
Background power used during active power-down | Pds(ACT_PDN) | 70.9 | mW | Psch(ACT_PDN) | 0.0 | mW | Psys(ACT_PDN) | 0.0 | mW
Background power used during active standby | Pds(ACT_STBY) | 118.1 | mW | Psch(ACT_STBY) | 94.5 | mW | Psys(ACT_STBY) | 64.3 | mW
Background power to complete refreshes | Pds(REF) | 4.0 | mW | Psch(REF) | 4.0 | mW | Psys(REF) | 3.6 | mW
DRAM power for ACT/PRE commands | Pds(ACT) | 67.1 | mW | Psch(ACT) | 67.9 | mW | Psys(ACT) | 61.6 | mW
DRAM write power | Pds(WR) | 259.9 | mW | Psch(WR) | 52.0 | mW | Psys(WR) | 35.4 | mW
DRAM read power | Pds(RD) | 228.4 | mW | Psch(RD) | 45.7 | mW | Psys(RD) | 31.1 | mW
DQ output power | Pds(DQ) | 66.0 | mW | Psch(DQ) | 13.2 | mW | Psys(DQ) | 13.2 | mW
Term power for writes | Pds(termW) | 102.3 | mW | Psch(termW) | 20.5 | mW | Psys(termW) | 20.5 | mW
Term power for reads from another rank | Pds(termRoth) | 152.0 | mW | Psch(termRoth) | 15.2 | mW | Psys(termRoth) | 15.2 | mW
Term power for writes from another rank | Pds(termWoth) | 145.2 | mW | Psch(termWoth) | 14.5 | mW | Psys(termWoth) | 14.5 | mW
 |  |  |  |  | Total DRAM Power Consumed |  |  | 273.3 | mW

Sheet: Summary
1Gb DDR3 SDRAM with 8 DQs and a -187E Speed Grade
 |  | System is operating at 400 MHz clock with VDD = 1.5V. Read bandwidth is 160 MT/s with write bandwidth of 160 MT/s. The DRAM terminates 160 MT/s. ACT commands are separated by 50ns on average. All parameters are calculated and require no user input.
 | Power Consumption Summary
 | Psys(PRE_PDN) |  | 0.0 | mW
 | Psys(PRE_STBY) |  | 13.9 | mW
 | Psys(ACT_PDN) |  | 0.0 | mW
 | Psys(ACT_STBY) |  | 64.3 | mW
 | Psys(REF) |  | 3.6 | mW
 |  | Total Background Power | 81.8 | mW
 | Psys(ACT) |  | 61.6 | mW
 |  | Total Activate Power | 61.6 | mW
 | Psys(WR) |  | 35.4 | mW
 | Psys(RD) |  | 31.1 | mW
 | Psys(DQ) |  | 13.2 | mW
 | Psys(TERM) |  | 50.2 | mW
 |  | Total RD/WR/Term Power | 129.8 | mW
 | Total DDR3 SDRAM Power |  | 273.3 | mW

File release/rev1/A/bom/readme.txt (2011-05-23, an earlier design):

roach2_bom.csv: The BOM as generated by Altium, NOPOP components are included
nopops.txt: A list of components in the BOM and indicated on the schematic that are not to be populated
roach2_bom_nopop.csv: The BOM altered to remove the NOPOP components

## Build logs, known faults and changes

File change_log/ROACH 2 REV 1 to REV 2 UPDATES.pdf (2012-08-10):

## ROACH 2 REV 2 UPDATES

- Most changes involve isolating the 3V3 and 3V3AUX devices to prevent backpowering.
- Splitting of I2C Bus between the 3V3 and 3V3AUX devices.
- 6.8mm Battery Holder replaced with a CR2032 (20mm) Battery holder.
- Crystal oscillator (for PPC) replaced with a clock oscillator.
- Additonal PPC LED and redesigned LED layout.
- Some ZDOK data lines have been swapped around.
- JTAG Isolation.
- Redesigned “POWER OVERRIDE” AND “AUTO START” circuits.
- Full list of changes can be found in the Roach 2 pre-production readiness Document.

Some of the changes are indicated in the diagram below :

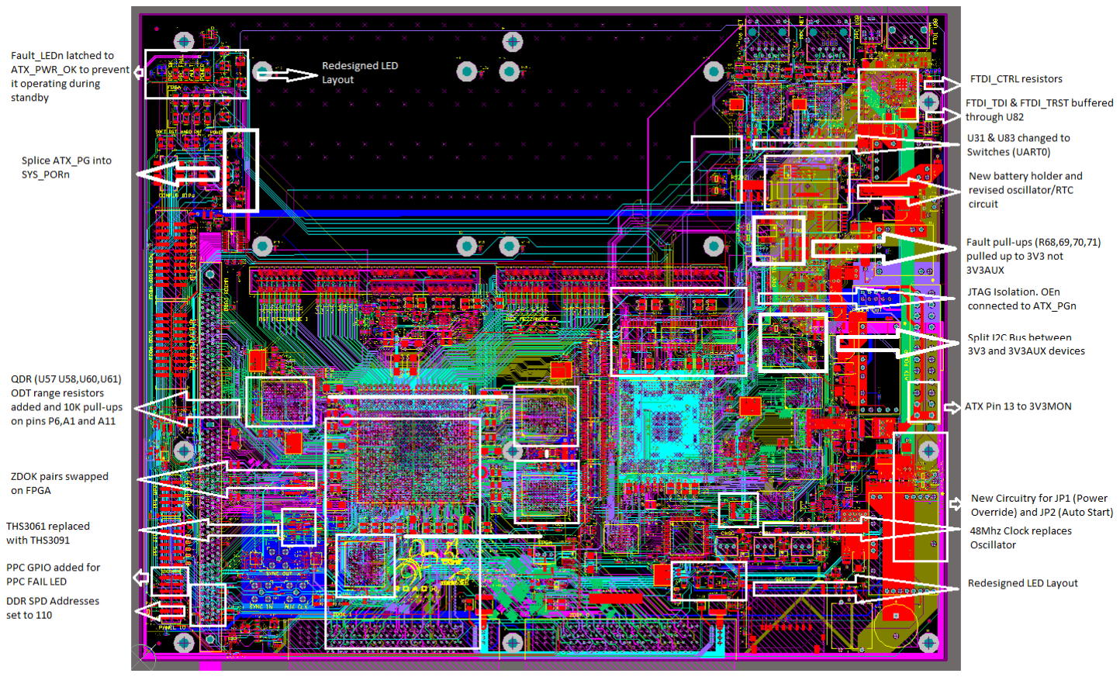
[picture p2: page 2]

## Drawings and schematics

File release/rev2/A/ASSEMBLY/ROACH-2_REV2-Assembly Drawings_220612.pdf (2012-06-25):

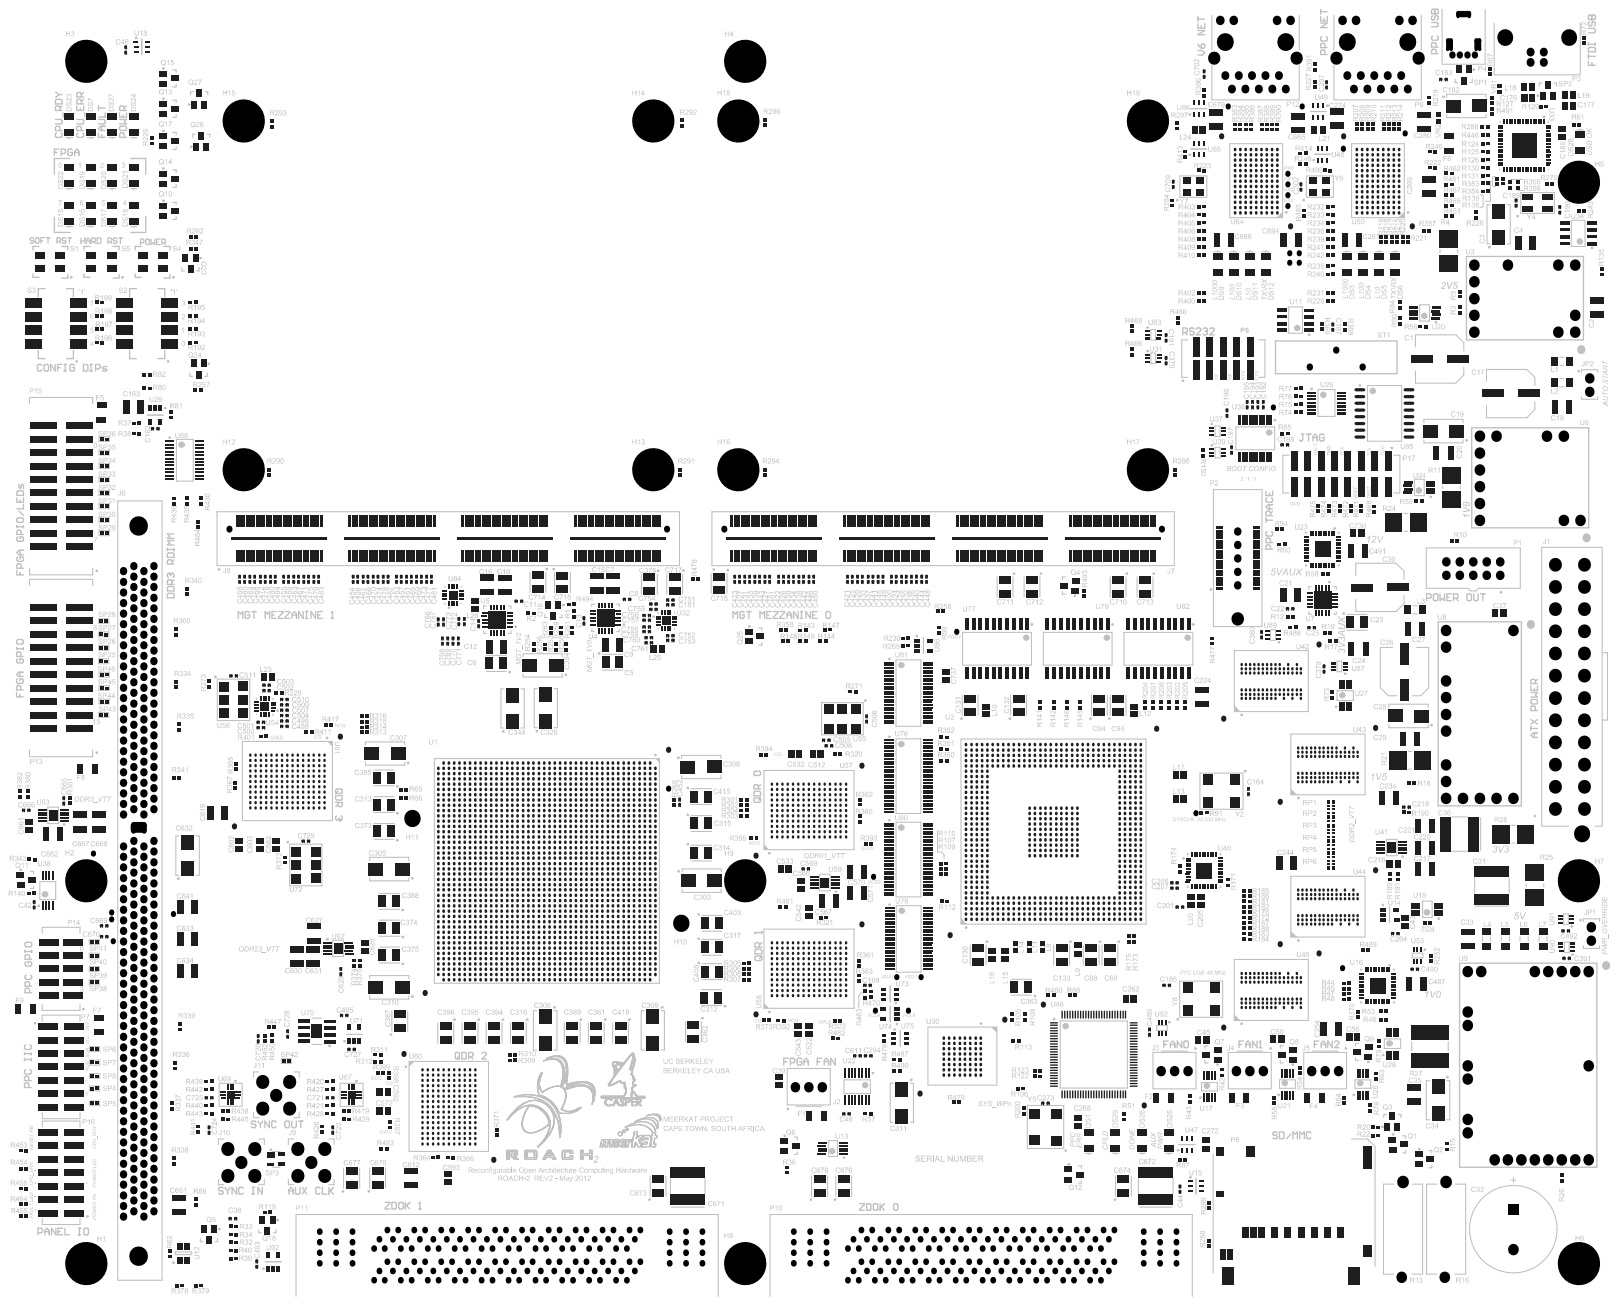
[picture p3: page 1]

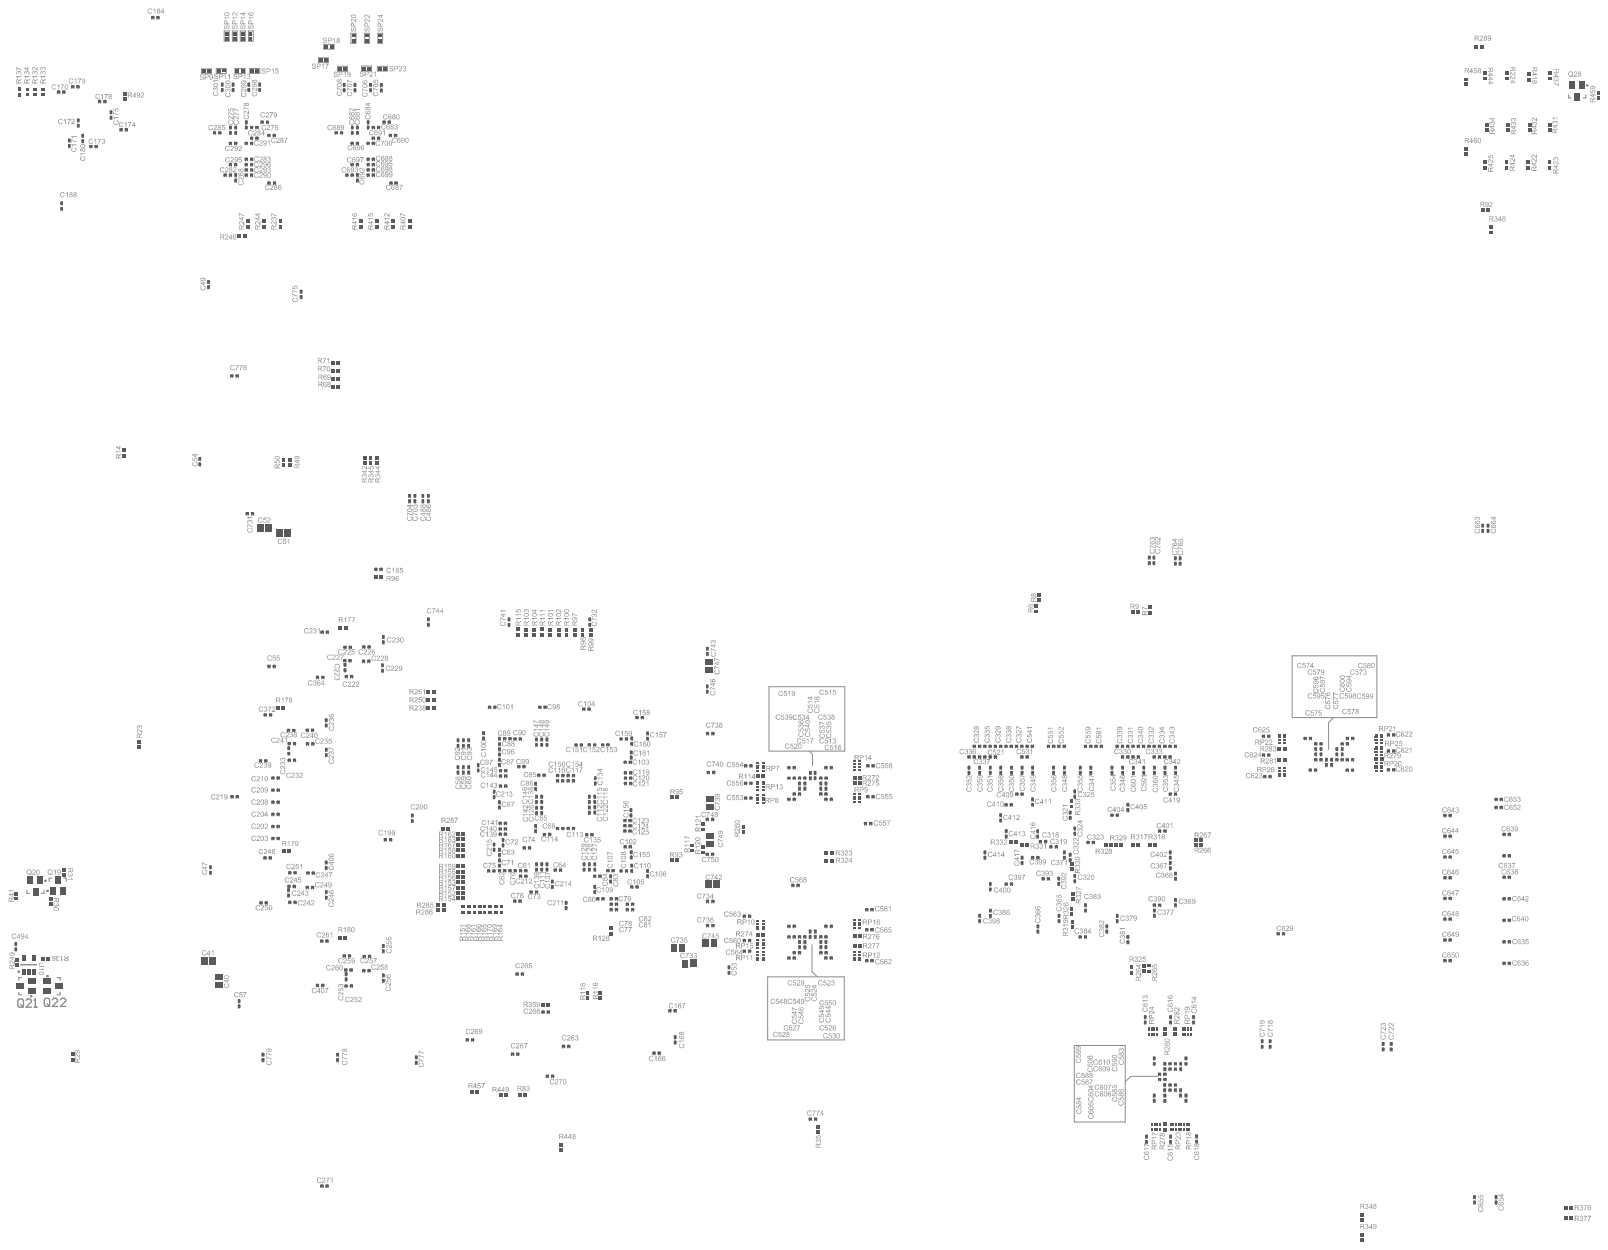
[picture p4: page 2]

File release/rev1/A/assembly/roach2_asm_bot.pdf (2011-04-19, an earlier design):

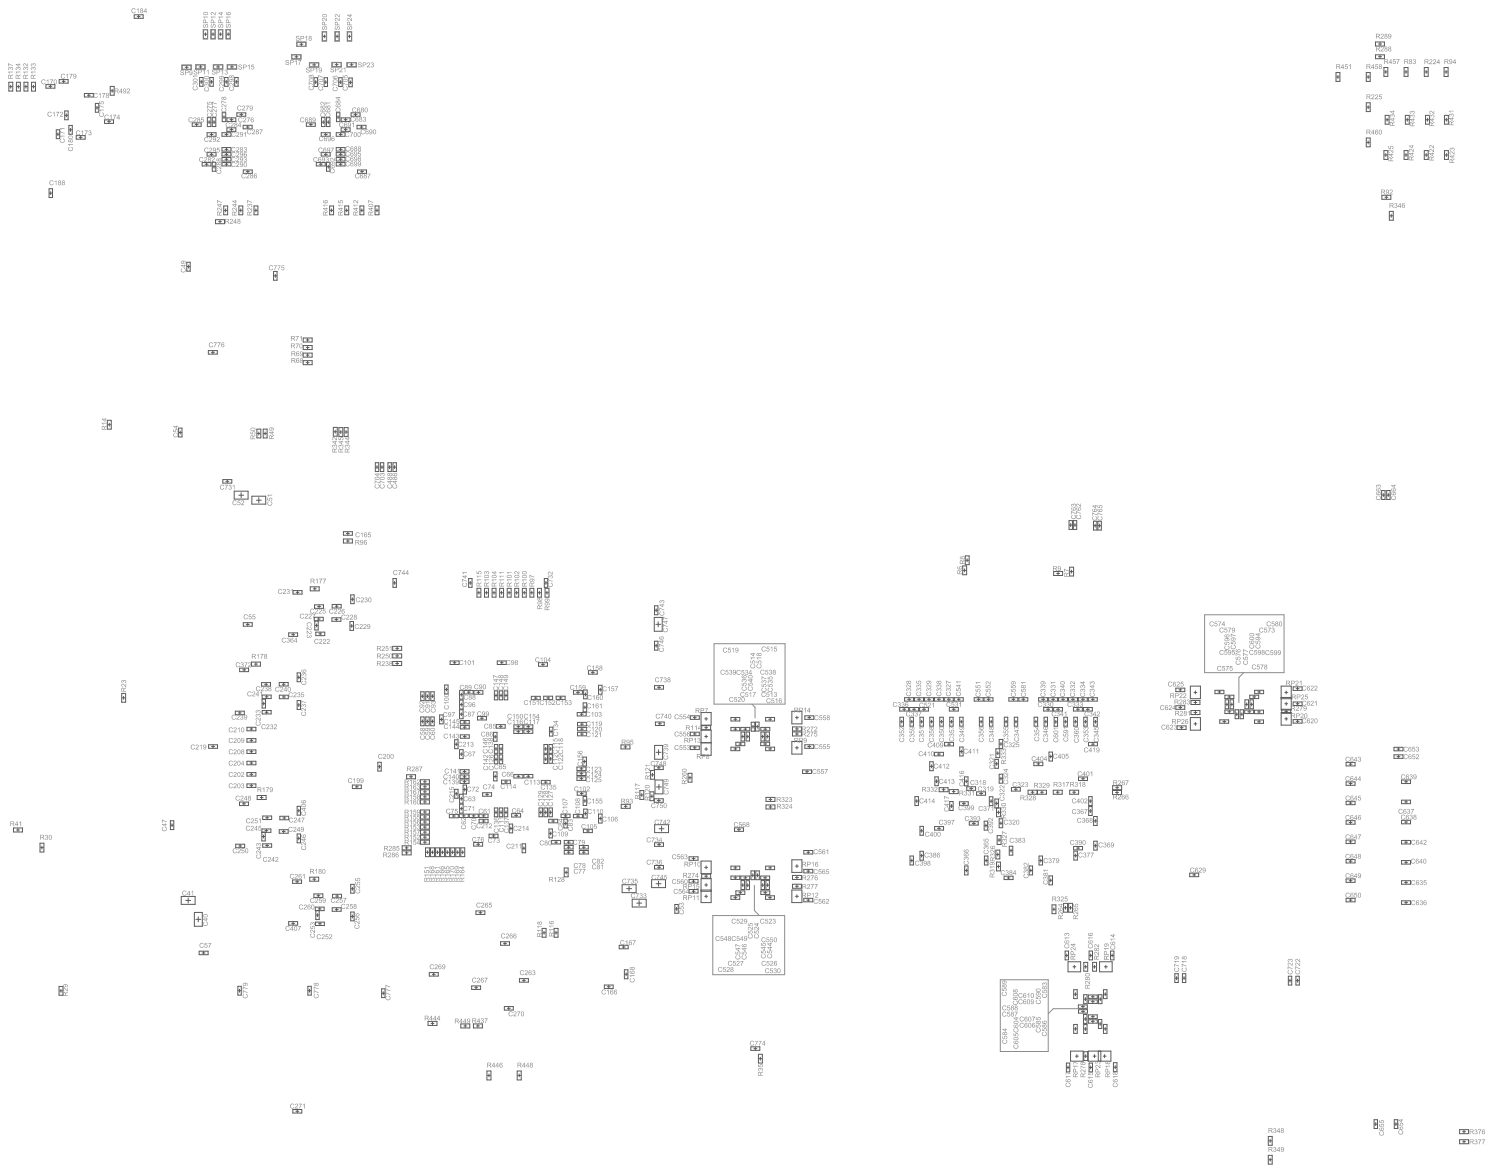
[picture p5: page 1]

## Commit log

2009-11-05 Added roach2 altium project ppc_power schematic complete
    [default.SchDoc, ppc_power.SchDoc, roach2_project.PrjPCB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]
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2009-11-23 Prelim completed serial interface (UARTS/USB) Prelim completed ext busses (PCI/EPB)
    [ppc_extbus.SchDoc, ppc_serial.SchDoc]
2009-11-25 Various changes to ppc_ddr2.SchDoc
    [ppc_ddr2.SchDoc]
2009-12-07 Added ppc sys/cpld/net schematics
    [ppc_ddr2.SchDoc, ppc_extbus.SchDoc, ppc_net.SchDoc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]
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2009-12-15 added symbol generation script + pin outs for ddr3 and V6
    [240-pin_ddr3_dimm.csv, 6vsx475tff1759pkg.csv]
2009-12-18 Added DDR3 schematic Added FTDI USB UART/Multifunction to ppc_serial.SchDoc A few tweaks
    [ddr3.SchDoc, ppc_serial.SchDoc, qdr0_1.SchDoc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]
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2010-02-05 First run of IO allocation complete work on mgts
    [ppc_extbus.SchDoc, qdr0_1.SchDoc, roach2_project.PrjPCB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]
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2010-02-26 Added samtec/mgt breakout content Added GPIO translator stuff Swapped around transceivers
    [jtag_levelxlate.SchDoc, mgt_breakout.SchDoc, power_supply.SchDoc]
2010-03-01 Level translation/JTAG buffering done GPIO block nearly complete, need 50ohm TTL amplifier
    [gpio_led.SchDoc, jtag_levelxlate.SchDoc, power_supply.SchDoc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]
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2010-03-05 added new roach2 block diagram updated power estimate to include sense table lots of work on todos, mainly regarding sense resistors
    [gpio_led.SchDoc, hwmon.SchDoc, jtag_levelxlate.SchDoc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]
2010-03-12 Added protection to 12V fan header Fixed bad translate buffer connection, direction is now controlled by v6 added pullups to mdio or v6 and ppc net set jtag voltage to 3v3aux changed push button cont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
    [ddr3.SchDoc, gpio_led.SchDoc, hwmon.SchDoc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]
2010-03-30 Changed PPC DRAM from DIMMs to Chips Added refdes for new circuitry
    [gpio_led.SchDoc, ppc_ddr2_0.SchDoc, ppc_ddr2_1.SchDoc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]
2010-03-31 Moved single ended GPIO so [0:9] will not be lost on smaller device
    [v6_io_27_28_32_33.SchDoc, v6_io_34_35_36_37_38.SchDoc]
2010-04-07 Complete overhaul nearly finished, too many changes to note
    [ddr3.SchDoc, gpio_led.SchDoc, hwmon.SchDoc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]
2010-04-08 roach2 now design completely overhauled for database libraries
    [ddr3.SchDoc, gpio_led.SchDoc, hwmon.SchDoc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]
2010-05-07 Added unplaced roach2 pcb, which includes several errors
    [ddr3.SchDoc, gpio_led.SchDoc, hwmon.SchDoc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]
2010-05-07 Fixed many connection error linked to footprint or symbol errors
    [ddr3.SchDoc, gpio_led.SchDoc, hwmon.SchDoc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]
2010-05-11 Added missing MISC schematic (for mounting holes etc) Changed USB connector to vertical MOLEX 0894858001
    [hwmon.SchDoc, misc.SchDoc, ppc_serial.SchDoc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]
2010-05-17 Added test-points for load testing changed ftdi powering scheme to use 3v3aux
    [gpio_led.SchDoc, misc.SchDoc, ppc_serial.SchDoc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]
2010-05-19 Added ESD protection diodes to v6 GPIO, PPC GPIO, PPC IIC headers and RJ45 inputs Changed Tantalum capacitors on 12V to electrolytic Added mgt breakout clock buffers and reordered IO
    [gpio_led.SchDoc, mgt_breakout.SchDoc, misc.SchDoc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]
2010-05-24 Removed 1x bypass cap per max16071 Added ds32kHz temperature controlled oscillator Lots of placement work, hwmon section done
    [hwmon.SchDoc, power_supply.SchDoc, ppc_ddr2_0.SchDoc]
2010-05-26 Changed FTDI and USB clocks to smaller 3mm crystals removed some 0 ohms resistors on marvell phys Added GND connections to various resonators Lots of placement work
    [hwmon.SchDoc, ppc_net.SchDoc, ppc_serial.SchDoc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]
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2010-05-27 Lots of placement work Pinswapped: epb tranlation buffers, CPLD CPLD Swapped a 4.7uF with a 100nf Added ESD protection to SMA output fixed incorrect RTC crystal label Added FET buffer to FAULT for LE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
    [gpio_led.SchDoc, hwmon.SchDoc, jtag_levelxlate.SchDoc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]
2010-06-01 Lots of work on placement, including MGT stuff Lots of schematic changes: Increased values on ZDOK bulk caps removed bulk caps(non power supply) from QDR01_VTT Added termination to unused SY89832 out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
    [ddr3.SchDoc, gpio_led.SchDoc, mgt_breakout.SchDoc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]
2010-06-02 Schematic changes: deleted 3 47uf caps from v6 io banks moved sma protection point removed 4.7uF from analogue block 2V5
    [gpio_led.SchDoc, roach2_project.PrjPCB, v6_config_io_16_17_21_22.SchDoc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]
2010-06-03 Layout: Synced all footprints with library All placement bar under BGA done Schematics: Fixed spelling error in device compatibility note Change EPB.rdy translation to use 2 input and gate added EPB 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
    [gpio_led.SchDoc, hwmon.SchDoc, jtag_levelxlate.SchDoc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]
2010-06-07 Not sure about schematic changes Added temporary ROACH Artwork
    [hwmon.SchDoc, power_supply.SchDoc, roach2_project.PrjPCB]
2010-06-10 removed floating net label in extbus lots of layout work
    [gpio_led.SchDoc, hwmon.SchDoc, power_supply.SchDoc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]
2010-06-11 Added a 100nf cap per dram chip Updated some footprints placed decoupling under 1 dram chip
    [ppc_ddr2_1.SchDoc]
2010-06-15 Schematics Removed 1x0.1uf on 1V8 and 1V5 per QDR Swapped QDR 2 and 3's 0.1uf caps Removed QDR negative echo clock test points (CQn) Grouped QDR control termination into resistor packs
    Layout
    QDR Fanout/0402 placement done
    V6 Fanout started
    [qdr0_1.SchDoc, qdr2_3.SchDoc, roach2_project.PrjPCB]
2010-06-17 Schematics: Added several 0.47uf caps to MGT_VTT Changed several MGT vtt/vss 4.7uf caps to 0.47uf Layout: All components placed
    [hwmon.SchDoc, v6_config_io_16_17_21_22.SchDoc, v6_io_12_13_14_15.SchDoc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]
2010-06-18 Changed to Marvel 88E1111 TFBGA-117 Package for both 1Ge PHYs Added jumper to v6net CLK changed IO voltage on clocks 1Ge clocks to 2V5 (Still need to change component to 2V5 Version) Removed 1x0.1uF 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
    [ppc_net.SchDoc, v6_net.SchDoc]
2010-06-21 Schematic: Fixed incorrect PPC USB data polarity Changed ZDOK clk names to make them diffpair directive compatible Renamed PPC DRAM nets to be diffpair directive compatible Added net labels to USB in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
    [ddr3.SchDoc, gpio_led.SchDoc, ppc_ddr2_0.SchDoc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]
2010-06-21 Lots of work at squishing DRC errors
    [roach2_project.PrjPCB]
2010-06-30 swapped mgt rx pins routed mgt rx lines
    [mgt_breakout.SchDoc, power_supply.SchDoc, ppc_net.SchDoc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]
2010-07-03 Some routing work, including pin swapping
    [mgt_breakout.SchDoc, roach2_project.PrjPCB, v6_config_io_16_17_21_22.SchDoc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]
2010-07-16 Lots of pin swapping, qdr2 routed
    [jtag_levelxlate.SchDoc, ppc_ddr2_0.SchDoc, ppc_sys.SchDoc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]
2010-07-19 Lots of pin swapping.
    QDRs all routed
    DDR3 50% routed
    [gpio_led.SchDoc, v6_config_io_16_17_21_22.SchDoc, v6_io_12_13_14_15.SchDoc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]
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2010-07-30 Lots of routing work; only ddr2 control lines remain.
    [gpio_led.SchDoc, power_supply.SchDoc, ppc_ddr2_0.SchDoc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]
2010-08-05 Updated mounting hole and testpoint footprints to resolve component clearances Made the mounting holes and test-points non-bom parts removed testpoints from MDIO on V6NET, FAULT lines, CPLD clock, 3V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
    [ddr3.SchDoc, gpio_led.SchDoc, hwmon.SchDoc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]
2010-08-06 Fixed logo collision issue Routed dram control line Matched dram groups Matched ZDOKs No unrouted nets
    [misc.SchDoc, roach2_project.PrjPCB]
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2010-08-13 Fixed mounting hole positions Various changes
    [gpio_led.SchDoc, ppc_sys.SchDoc, roach2_top.SchDoc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]
2010-08-30 Optimized ppc_net rgmii termination Added mounting holes for mezzanine cards
    [misc.SchDoc, ppc_extbus.SchDoc, ppc_net.SchDoc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]
2010-08-30 Deleted pdf schematic Added output and eco folders Updated output folders
    [roach2_project.PrjPCB]
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2010-09-02 Fixed lt2951 footprint Replaced obsolete linear regulator LD2979XX38 with lp2985
    [hwmon.SchDoc]
2010-09-02 Changed 1V8 & 2V5 tant caps to 4V 680uF Corrected several PTH turbo trans resistor values
    [power_supply.SchDoc]
2010-09-03 Fixed qmss connectors
    [mgt_breakout.SchDoc, power_supply.SchDoc]
2010-09-03 Changed SD/MMC card connector Placed mezzanine card holes
    [roach2_project.PrjPCB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]
2010-09-06 Increased the size of the ATX mounting holes Added some stitching via in mezzanine card area
    [roach2_project.PrjPCB]
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2010-09-20 Fixed 1v0 power supply connection on v6_power schematic Set soldermask expansion on pads to 2mil added covered via to ddr2 bgas, top and bottom changed ddr2 pads to 0.45 mm, adjacent vias changed to 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
    [ddr3.SchDoc, gpio_led.SchDoc, ppc_extbus.SchDoc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]
2010-09-21 (DONE) Resolved most DRCs (DONE) Changed LTC2951 TSOT-23/TS8 footprint to avoid soldermask slivers (DONE) Changed ADCMP604 footprint to avoid soldermask slivers (DONE) Massaged nets around various no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
    [roach2_project.PrjPCB]
2010-09-21 Added pads to all non-plated through-holes Fixed AUX power header Neatened C182 connections Length matched qdr k/kns Added SelectMap dout_busy to cpld added TP to SM Din Remote temp sense pins now ha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
    [hwmon.SchDoc, jtag_levelxlate.SchDoc, power_supply.SchDoc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]
2010-10-06 Major fix to the DCI sharing which resulted in the scrapping of the QDR byte enables
    [qdr0_1.SchDoc, qdr2_3.SchDoc, roach2_project.PrjPCB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]
2010-10-07 Cleaned up qdr termination islands Thickened some qdr vref traces removed dangling net on D1 removed a number of unuseful 0 ohm resistors, inserted one test point on the vmon reset Fixed P16 symbo lt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
    [gpio_led.SchDoc, hwmon.SchDoc, roach2_project.PrjPCB]
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2010-10-08 Tidied termination pack connections to ddr2 vtt Removed TODOs from schematics Changed battery scheme to socketed, added battery as mechanical item Changed date on PCB to October 2010 (sigh) Matched M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
    [hwmon.SchDoc, misc.SchDoc, ppc_serial.SchDoc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]
2010-10-11 Fixed power out header pinout labelling Made solder mask pullback on bgas 3mil Made solder mask pullback on large fine-pitched devices 2mil
    [power_supply.SchDoc, roach2_project.PrjPCB]
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2010-10-11 Added ROACH 2 REV 0 Release A Manufacturing Files
    [roach2_BOM.csv]
2010-10-26 Updated REV0 bom to fix incorrect part numbers for: IC-MON-4 IC-LOG-5 IC-PLD-1
    [roach2_BOM.csv]
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2011-04-04 Fixed Mantis #36: "Power out too close to ATX connector"
    Moved Power out connector P1, C30, C23 and C24. Made routing to changes to support this. DRC check OK.
    [roach2_project.PrjPCB]
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2011-04-04 Mantis #49 "Add V6 GPIOs"
    Replaced existing I2C headers with a single header. Moved PPC header below mounting hole. Added 4xV6_GPIOs. Replaced exiting second V6 GPIO header with 8x boxed header. Various routing tweaks to facilitate changes.
    [gpio_led.SchDoc, ppc_extbus.SchDoc, ppc_serial.SchDoc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]
2011-04-04 Mantis #48 Removed FPGA boot scheme; flash_csn connects directly
    [ppc_extbus.SchDoc, roach2_top.SchDoc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]
2011-04-04 A number of smaller mantis issue fixes.
    Issue 46: Incorrect signal name: UART0_CTSn-BC2
    Issue 47: vias under qmss connector uncovered
    Issue 94: nets couples on layers 8 & 9
    Issue 86: RTC U11 has supply on 3V3AUX , should be 5vAUX
    Issue 84: RTC U11 has SDA and SCL swapped
    Issue 77: VCCJTAG should be tied to 3V3
    Issue 75: act_led should be driven from 5V
    Issue 74: V6 LED Part no.'s overlap on schematic
    Issue 73: marvell debug should be removed
    Issue 72: Config DIP text on schematic should be scrapped
    Issue 71: VR1/2 should have part number indicated on schematic
    Issue 70: Unused input pins on U25 should be tied low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
    [gpio_led.SchDoc, hwmon.SchDoc, jtag_levelxlate.SchDoc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]
2011-04-04 A number of mantis issue resolutions:
    Mantis issue #40: Multiple CPLD connections on SYS_WPn
    Mantis issue #44: LED inverters should have same voltage as current limiting resistors
    Mantis issue #53: JTAG pullups
    Mantis issue #54: 1Ge JTAG signals wrong on both PHYs
    Mantis issue #60: covered vias under QFNs with thermal pad
    Mantis issue #61: perclk on wrong site
    Mantis issue #63: Programming CPLD with bad image can break JTAG chain
    Mantis issue #66: Configuration for V6 1Ge PHY incorrect
    Mantis issue #67: Connect V6 1Ge PHY MDIO to PPC
    Mantis issue #69: Thermal isolation on ambient temperature sensors
    Mantis issue #95: qdr2 k/kn not routed ideally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
    [gpio_led.SchDoc, jtag_levelxlate.SchDoc, ppc_net.SchDoc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]
2011-04-05 A number of mantis issues fixed:
    Mantis issue #55: FTDI eeprom footprint incorrect
    Mantis issue #41: No PPC GPIO connection with FTDI chip
    Mantis issue #90: FTDI symbol has channel incorrectly labelled
    Mantis issue #56: LED for FTDI
    Mantis issue #57: LED for CPLD
    Mantis issue #76: green status leds not labled, and placement not ideal
    [ppc_serial.SchDoc, ppc_sys.SchDoc, roach2_project.PrjPCB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]
2011-04-05 Various Mantis issue fixes
    Mantis issue #99: push-button reset not working reliably
    Mantis issue #87: eeprom i2c address 0x55 not indicated on SCH
    Mantis issue #64: Signal integrity on CCLK/PERCLK not adequate
    Mantis issue #91: MMC CDn and WPn incorrect
    Mantis issue #89: Various issues with U70
    [gpio_led.SchDoc, hwmon.SchDoc, jtag_levelxlate.SchDoc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]
2011-04-05 Fixed mantis issue #39: Silkscreen slivers on vias
    The issue should really read "Soldermask slivers near several vias". Oh well. It's fixed now; no DRC errors with a soldermask sliver size of 3.7 mil.
2011-04-08 Fixes for two mantis issues:
    Mantis issue #37: Back panel connectors do not align
    Mantis issue #38: Type-B USB connector will not make contact with front panel
    The USB-B connector is by default a shielded molex part, but remains compatible with the old tyco part.
    Also added 0-ohm resistors to shield pins. This give flexibility in shielding options and also should improve
    solderability on those pins which will improve stability.
    [ppc_serial.SchDoc]
2011-04-08 Fixed mantis issue #34: Silkscreen logos not clear
    Simply thickened the logo lines. It seems to be okay.
2011-04-11 Fixed mantis issue #68: Marvell PHY LED setup not quite working as intended
    The RX and DUPLEX LEDs have been scrapped. The TX is now AND'ed with itself to go to the jack LED, effectively as a buffer.
    RX and DUPLEX now have testpoints.
    Unrelated fix:
    JTAG TCK and TRST are pulled up to 3V3AUX as the MAX16071 ICs are powered off of that supply.
    Minor tweak:
    Altium schematics should now be listed as the same order as page numbers in project view
    [jtag_levelxlate.SchDoc, ppc_net.SchDoc, roach2_project.PrjPCB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]
2011-04-11 resolved mantis issue #98: Scheme to isolate sections of the JTAG chain
    Should now be able to isolate jtag the PPC, V6 and CPLD from the rest of the chain, by driving an FTDI GPIO.
    [hwmon.SchDoc, jtag_levelxlate.SchDoc, ppc_serial.SchDoc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]
2011-04-11 Fixed mantis #42: consolidate passive components
    Changed as per mantis ticket except for CAP-CER-5 and CAP-CER-8. Remote temperature filter resistor changes to 49R9.
    [ddr3.SchDoc, gpio_led.SchDoc, hwmon.SchDoc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]
2011-04-11 missed change 47 -> 49R9 in last check-in
    [ppc_net.SchDoc, v6_net.SchDoc]
2011-04-12 resolved mantis issue #92: Issues with MAX16071
    No satisfactory answer has been provided from Maxim about the ABP/DBP/VCC tied to 3V3 issue. They have recommended we use 5V as the supply and bypass ABP and DBP to ground, which has been implemented.
    TMS and TCK connections have been fixed.
    The fanout has been changed so no vias go underneath the package. There have also been a number of routing tweaks to facilitate this.
    [hwmon.SchDoc]
2011-04-12 Resolved mantis issue #59: Back-powering from 3v3 AUX
    Added buffers on offending UART signals and added switches on offending I2C lines.
    [ppc_serial.SchDoc]
2011-04-15 Fixed mantis issue #97: Xilinx MIG not happy with IO allocation
    It would be a huge amount of work to make the ucf MIG compatible. What I have done is at least made the default controller compilable. This should work, just with a few performance knocks.
    [roach2_project.PrjPCB, v6_config_io_16_17_21_22.SchDoc, v6_io_12_13_14_15.SchDoc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]
2011-04-18 Fixed floating connections on TRC, U80-30 and SYS_WPn.
    Added pull-ups/-downs to boot config and sys_wpn
    covered one via under max16071
    [jtag_levelxlate.SchDoc, ppc_serial.SchDoc, ppc_sys.SchDoc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]
2011-04-18 Fairly dodgy fix for the mantis issue #101: Reset/Powerup button behaviour not ideal
    Completely redone scheme. Now use lt2954-1, which requires you to hold the push-button.
    [gpio_led.SchDoc, hwmon.SchDoc, power_supply.SchDoc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]
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2011-04-19 A number of tweaks while closing issue.
    Board is ready for REV1 output file generation.
    [jtag_levelxlate.SchDoc, power_supply.SchDoc, ppc_serial.SchDoc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]
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2011-05-16 Fixed "Neck-down" problem on ZDOK0 N15 as reported by DDI
    [roach2_project.PrjPCB]
2011-05-16 Synced gerbers with pcb, added NC drill files
    [roach2.DRL, roach2.GBL, roach2.GBP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]
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2011-05-23 remove 17k3 resistor, replaced with 17k4 change halo part to 1g-12
    [roach2_bom_nopop.csv]
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2011-08-16 Changed nopop bom to comma delimiters added C37 to nopops
    [roach2_bom_nopop.csv]
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2012-02-08 Trying to create revision control, this being rev 2 schematics.
    [ddr3.SchDoc, gpio_led.SchDoc, hwmon.SchDoc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]
2012-06-25 Moving svn commits to github
    Once the svn repo was moved commits continued to be made into svn.
    I am adding the changes to github. If anything is missing speakt to
    phil.
    [K3000-0176_B.PcbDoc, K3000-0176_B.SchDoc, LEDs.SchDoc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]
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2013-05-23 Updating BOM
    Added new DDR 2 and Alternative DDR3 components to the BOM.
    [ROACH-2_REV2_BOM.csv]
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
